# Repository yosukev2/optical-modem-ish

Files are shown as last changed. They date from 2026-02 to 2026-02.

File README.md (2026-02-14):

了解。以下はそのまま `README.md` に貼れる形で作りました（**W1時点のREADME**として、W2以降で埋める前提の“空枠”も入れてあります）。

---

# Optical Link Modem (RP2040 + TOSLINK)

## 目的（1〜2行）

RP2040(Pico) と TOSLINK 光モジュールを使い、**「基板 + 組み込みFW + 検証（BER/PER・ログ）+ 実務ドキュメント」**まで揃えた、実務代替ポートフォリオとしての“光リンクモデム”を実装する。

---

## 構成（箇条書き）

* **PC**

  * USB/シリアルで CLI 操作・ログ取得
* **MCU（RP2040 / Raspberry Pi Pico）**

  * フレーミング / 同期 / CRC / 再送 / 符号化モード切替
  * BER/PER 測定とログ出力
* **光モジュール（TOSLINK推奨）**

  * Tx：TOTX/TOTX系
  * Rx：TORX/TORX系
* **光ファイバ（TOSLINKケーブル）**

  * Tx↔Rx を接続（短距離から開始）
* **ベースボード（Pico載せ替え可能）**

  * 3.3V電源（LDO/DC-DC）＋保護＋テストパッド
  * Tx/Rxモジュール搭載、計測点、拡張I/F

> 構成図（W22で差し替え予定）
> `docs/onepager_A4.pdf` に掲載予定

---

## 成果物一覧（実務扱いに変える成果物）

* **Bring-up手順**：`docs/bringup.md`

  * 電源 → クロック → I/O → Tx → Rx → リンク確立（写真・測定値つき）
* **テスト計画**：`docs/test_plan.md` / `docs/test_matrix.csv`

  * 条件・合否基準・ログ形式・自動化手順
* **不具合チケット（最低3件）**：`docs/bugs/`（またはGitHub Issues）

  * 再現 → 切り分け → 修正 → 再発防止 → テスト追加
* **A4一枚サマリ**：`docs/onepager_A4.pdf`

  * 構成図、担当範囲、検証結果（BER/PER）、学び、残課題

---

## 週次マイルストーン（W1〜W4）

### W1：要件固定＆“実務の型”を作る

* `docs/spec.md`：仕様凍結（物理/レート/フレーム/CRC/再送/ログ）
* リポジトリ構成確定（docs/fw/hw/tools）
* Issueテンプレ追加（bug運用の型）

### W2：最速プロトで光リンクを“観測”する

* ブレッドボード等で Tx/Rx を暫定配線
* GPIOトグル → 受光出力変化を観測（ロジアナ/オシロ推奨）
* `docs/bringup.md` に配線図・測定ポイントを追記
* `fw/blink_optical/`：トグル＋Rxカウント最小FW

### W3：フレーム + CRC を“最低限のモデム核”として実装

* フレーム：`Preamble | Sync | Header | Length | Payload | CRC`
* 送受信バッファ（リング）・エラー処理
* `tools/test_crc.py`：CRCの既知ベクタテスト
* `docs/protocol.md`：プロトコル仕様

### W4：同期（プリアンブル検出）＋PER計測で“モデム顔”にする

* 受信同期：プリアンブル検出→sync→header→payload→CRC
* PER測定（連番pkt、欠番/CRC NG分類）
* ログフォーマット確定：`docs/log_format.md`
* READMEにデモ手順追記（このREADMEの空枠を埋める）

---

## デモ手順（W2で追記する前提の“空枠”）

> ※ここは W2 以降に更新予定

### 1) 配線・準備

* [ ] Tx/Rxモジュールの接続（Vcc/GND/IN/OUT）
* [ ] TOSLINKケーブルで Tx → Rx 接続
* [ ] Pico をPCに接続（USB）

### 2) ビルド＆書き込み

* [ ] `fw/` のビルド手順（例：CMake / pico-sdk）
* [ ] Picoにフラッシュ

### 3) 動作確認（最小）

* [ ] Txトグルを出す
* [ ] Rxでエッジカウント
* [ ] ロジアナで Tx入力とRx出力を観測（任意）

### 4) 測定（予定）

* [ ] PER測定（`test per ...`）
* [ ] BER測定（`test ber ...`）
* [ ] ログ保存（CSV/JSONL）

---

## 必要機材

* **Raspberry Pi Pico（RP2040）** ×2（送受信を分けるなら2枚推奨）
* **TOSLINK Tx/Rx モジュール**
  * 推奨：Toshiba系（TOTX/TORX など 3.3V対応の系統優先）
  * 代替：PLT133系（3〜5V/TTL互換と記載の系統）
* **TOSLINK光ファイバケーブル**（短め推奨）
* **ロジックアナライザ**（Tx入力/Rx出力の波形確認）
* **オシロスコープ**（電源リップル・受光ノイズ確認）⇒使用したいが、一旦保留
* **可変電源＋電流制限**（基板Bring-upの安全性UP）⇒使用したいが、一旦保留

---

## リポジトリ構成（予定）

```
.
├─ docs/            # 仕様・設計・bring-up・テスト・レポート
├─ fw/              # RP2040 firmware（link/protocol/cli/test）
├─ hw/              # KiCad（schematic/pcb/gerber）
├─ tools/           # PC側スクリプト（sweep/log/plot 等）
└─ sample_logs/     # サンプルログ（後で追加）
```

---

## ライセンス

* TBD（例：MIT / Apache-2.0）

---

## 状態

* W1（仕様凍結＆実務の型づくり）進行中

---

必要なら次に、**READMEの冒頭に入れる「3行で刺す要約」**と、`docs/spec.md` の雛形（項目埋め済み）も同時に作って、W1の成果物を一気に揃える形にできます。

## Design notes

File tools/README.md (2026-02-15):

# tools/README.md
目的：ログ取得・PER/BER集計に加えて `circuit_synth` を使うため、`uv` でPython環境を固定する。

---

## 1. Python方針
- 依存管理：`uv`（`pyproject.toml` + `uv.lock`）
- Python：3.12 以上（`circuit_synth` の要件）
- 仮想環境：`tools/.venv`（`uv` が自動作成）

---

## 2. セットアップ
1) `tools` に移動  
2) 依存を同期  
   `uv sync`  
3) 動作確認  
   `uv run python -c "import circuit_synth as cs; print(cs.__version__)"`

---

## 3. 主要パッケージ
- circuit_synth（回路生成）
- pyserial（UARTログ取得）
- pandas（CSV集計）
- rich（CLI表示）

---

## 4. 補足
- PDF出力を使う場合は `reportlab` が必要なため、必要時に `uv add reportlab` を実行する。

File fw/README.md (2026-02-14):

# fw/README.md
目的：W2で "必ずビルドして.uf2を作る" ための最小手順を固定する。

---

## 1. 前提
- OS：Windows（PowerShell想定）
- ボード：Raspberry Pi Pico (RP2040)
- SDK：pico-sdk **2.2.0 固定**（タグ固定。master追従しない）

---

## 2. 依存（インストール済みチェック）
必要：
- Git
- CMake
- Ninja（推奨）
- ARM GCC toolchain（arm-none-eabi-gcc）
- Python（ビルド補助で使う場合あり）

---

## 3. pico-sdk を取得（サブモジュール or 直clone）
推奨：repo直下に external/pico-sdk として置く

例：
- external/pico-sdk を作って clone
- tag 2.2.0 に checkout

---

## 4. ビルド手順（最小）
例：fw/blink をビルドする想定（W2はLED点滅でOK）

1) ビルドディレクトリ作成
2) cmake configure
3) ninja で build
4) .uf2 を Pico に書き込み

[TODO] 実際の fw 構成に合わせてコマンドを確定する

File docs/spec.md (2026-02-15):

# Spec: Optical Link Modem (RP2040 + PLT133/PLR237)

> SPEC FREEZE (v0.1 / W1)  
> 本仕様は原則確定版。変更が必要な場合は Issue 経由で、理由・影響範囲・代替案・必要なテスト更新（test_plan / log_format 等）を明記した後に反映。

## 0. 関連ドキュメント（正）
- Protocol詳細（フレーム/同期/状態遷移）: `docs/protocol.md`
- ログ列定義（CSVの一次ソース）: `docs/log_format.md`
- テスト計画（試験ID/合否基準/条件マトリクス）: `docs/test_plan.md`
- CLI仕様: `docs/cli.md`
- 部品根拠（データシート抜粋/購入リンク/代替候補）: `docs/parts.md`
- ハードウェア契約の正本（ネット名/IF契約/生成運用）: `docs/hw/`

---

## 1. 目的
PLT133（Tx）/PLR237（Rx）のTOSLINK系モジュールを用いた低速の光リンクで、“モデムっぽい”通信FW（フレーミング/同期/CRC/再送/符号化モード切替）と、検証（BER/PER・ログ）および 実務ドキュメント（Bring-up/Test plan/Bug tickets/Onepager）までを揃える。

## 2. スコープ
- 光リンク（短距離）での 双方向 送受信（最低2ノード、Tx/Rxを両方搭載）
- “モデムっぽさ”は ファーム側で実装（物理の難所は極力回避）
- 初期は「動く」より 測れる・再現できる・壊れ方が定義される を優先する

---

## 3. 固定仕様（W1で凍結する値）

### 3.1 ハード前提（部品・電圧）
- MCU: RP2040（Raspberry Pi Pico）
- Optical modules（Photolink系）
  - Tx: PLT133/T10W
  - Rx: PLR237/T10BK
- 部品の採用理由・一次ソース（データシート抜粋）・購入リンク・代替候補は `docs/parts.md` を正 とする（specは凍結運用のまま）
- GPIO Logic level: 3.3V
- Optical module Vcc:
  - Tx(Vcc)=3.3V
  - Rx(Vcc)=3.3V
  - 理由：Rx出力をRP2040の3.3V入力範囲に収めるため（Rxを5V駆動する場合はレベルシフタ必須。v0.1では禁止）

### 3.2 リンク形態
- Nodes: 2ノード想定（双方向 / Tx+Rx）
- Medium: TOSLINK光ファイバ

### 3.3 データレート
- 対応レート（設定可能）: 0.5 / 1 / 2 Mbps
- 初期運用（W2〜W4）: 0.5 Mbps 固定（安定化優先）

### 3.4 フレーム（概要）
- Frame format: `Preamble | Sync | Header | Length | Payload | CRC`
- Payload length: 0〜256 bytes（最大256B）
- CRC coverage: Header + Length + Payload（Preamble/Syncは除外）

### 3.5 同期（Preamble / Sync）
- Preamble
  - Pattern: 0x55 repeated
  - Count: 32 bytes（固定）
- Sync byte
  - Value: 0xD5（固定）
- 受信失敗時（CRC NG / 長さ不正 / sync不一致 等）は SYNC探索へ戻る（RESYNC）

### 3.6 Header（固定レイアウト）
Headerは 4 bytes固定。

| byte | name | size | meaning |
|---:|---|---:|---|
| 0 | version | 1 | 固定値 0x01（v0.1） |
| 1 | flags | 1 | mode/rate/power/ack等のビットフィールド |
| 2 | seq | 1 | 下位4bitのみ使用（0〜15）、上位4bitは0固定 |
| 3 | type | 1 | 0x01=DATA, 0x02=ACK, 0x03=NACK, 0x10=TEST |

#### flags（ビット割り当て）
- bit0-1: rate_id
  - 00=0.5Mbps, 01=1Mbps, 10=2Mbps, 11=reserved
- bit2: mode
  - 0=Mode A(NRZ), 1=Mode B(Manchester)
- bit3-4: power
  - 00=0, 01=1, 10=2, 11=reserved
- bit5: ack_req
  - 0=ACK不要, 1=ACK要求
- bit6-7: reserved（0固定）

### 3.7 CRC
- CRC Algorithm: CRC-16/CCITT-FALSE
  - width = 16
  - poly = 0x1021
  - init = 0xFFFF
  - refin = false
  - refout = false
  - xorout = 0x0000
- CRCの付与順（送信バイト順）: MSB first（big-endian）
  - 例：CRC=0x1234 → `0x12 0x34`
- CRCの入力順: Header → Length → Payload の順にバイト列を投入

### 3.8 再送（ARQ）
- ARQ: Stop-and-Wait
- seq: 4bit（0〜15）（Header.seq下位4bit）
- timeout: 20ms
- retry上限: 5回
- retry超過: link_down を宣言（statusに反映し、再同期を試みる）

### 3.9 符号化モード（PHY coding）
- Mode A: NRZ（W3〜で利用）
- Mode B: Manchester（W8で実装。仕様としてはv0.1で固定）
- モードの通知/切替: `flags.mode`

### 3.10 測定（品質評価）
- PER: packet error/loss rate（連番パケット、欠番/CRC NG を分類）
- BER: PRBS7（余力でPRBS15）

### 3.11 ログ（CSV）
- 保存先: `logs/`
- 命名規則: `logs/YYYYMMDD_runXX_<mode>_<rate>_<power>_<note>.csv`
  - 例：`logs/20260105_run01_A_0p5M_p1_short.csv`
- 列定義: `docs/log_format.md` を正（specは参照のみ）

---

## 4. 非目標（Non-goals）
- FEC（前方誤り訂正）
- 暗号化（Encryption）
- 高速化（>2Mbps）
- 長距離・高信頼向けのアナログ最適化（TIA設計、受光アンプ設計 等）
- 厳密な規格準拠（S/PDIF等）

---

## 5. インターフェース

### 5.1 PC ↔ MCU
- Control/CLI: USB CDC（優先）
  - 代替: UART
- Log output: USBまたはUART（制御と分離してもOK）

### 5.2 MCU ↔ Optical
- Tx: GPIO -> PLT133 IN
- Rx: PLR237 OUT -> GPIO input
- 実装方針: Rxは PIO or IRQ（W3で確定）

---

## 6. 合格条件（W26の最終成果物：1段落）
W26時点で、基板のBring-up手順（電源→I/O→リンク）が写真・測定値つきで再現可能であり、テスト計画（条件・合否基準・ログ形式）に基づいて BER/PERを自動測定しCSVログとして保存できること。さらに、不具合チケットを最低3件（再現→切り分け→修正→再発防止→テスト追加まで）完了しており、代表条件での測定結果（数値）をまとめた A4一枚サマリを提出できる状態であること。

---

## 7. 変更履歴
- 2025-12-30: 初版完成

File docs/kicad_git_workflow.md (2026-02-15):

# KiCadをGitで管理する運用
このドキュメントは、KiCadプロジェクトをGit/GitHubで安全に管理・レビューするための運用ルールを1箇所に集約したものです。  
**目的は「差分が追える」「衝突を避ける」「別PCでも再現できる」状態を維持すること**です。

---

## 1. リポジトリ構成（配置の原則）
**原則：KiCadプロジェクトは `hw/` 配下に置く。規約は `docs/` に集約する。**

hw/
  hw.kicad_pro
  hw.kicad_sch # Step00（正本）
  step01_power.kicad_sch # Step01以降
  (必要になったら) hw.kicad_pcb
  (必要になったら) sym-lib-table
  (必要になったら) fp-lib-table
lib/ # 外部ライブラリは必要時のみ（追加は別Issue）
docs/
  kicad_git_workflow.md # このファイル（運用の単一の真実）
  hw/
    nets.yml # ネット名辞書の正本（canonical）
    interface_contract.yml # Step間I/F契約の正本
    circuit_synth_policy.md # Circuit-Synth運用規約の正本
out/ # 生成物（原則git管理しない）

注意：`out/` は生成物置き場。普段はGitに入れない（リリース時だけ例外ルールあり）。

---

## 2. Gitで追跡するもの / ignoreするもの
KiCadはGUI編集だが、主要成果物はテキストファイルでありGit管理が可能。  
ただし個人環境ファイルや自動生成・バックアップ類は差分ノイズになるため除外する。

### 2.1 追跡（commit）対象（基本）
- `hw/*.kicad_pro`（プロジェクト設定。共有に有用なため原則追跡）
- `hw/*.kicad_sch`（回路図。Step分割前提）
- `hw/*.kicad_pcb`（基板。導入後は追跡）
- `hw/sym-lib-table` / `hw/fp-lib-table`（ライブラリ参照固定に有用。必要になったら追跡）
- `docs/` 配下（規約、設計ノート、意思決定ログ）

### 2.2 除外（ignore）対象（必須）
- `*.kicad_prl`（ユーザーごとの状態。必ず除外）
- `*-backups/`（バックアップフォルダ）
- `_autosave-*`（自動保存）
- `*.lck`（ロックファイル）
- `out/`（生成物置き場）
- `hw/out/`（`hw/` 配下の生成物置き場）

---

## 3. 回路図の分割方針（Step運用）と同時編集ルール
### 3.1 分割方針（Step01〜）
原則：回路図はStep単位のファイルに分割し、変更範囲を小さくする。

- `hw/hw.kicad_sch`：Step00（最上位／俯瞰と階層シートの接続点）
- `hw/step01_power.kicad_sch`：電源（W3でこのファイルを作る方針）
- `hw/step02_*`：I/OやTOSLINK周辺
- `hw/step03_*`：MCU周り
- 以降、必要に応じて `stepNN_*` を追加

命名規則：
- `hw/stepNN_<short>.kicad_sch`（NN=01,02... / shortは小文字スネーク）
- CIでは `^hw/step[0-9][0-9]_[^/]+\.kicad_sch$` を強制する（`hw/hw.kicad_sch` はStep00として別扱い）
- 一度決めたファイル名は原則変更しない（差分追跡コストを上げるため）

### 3.2 同時編集しないルール（コンフリクト回避の最重要）
- 同じ `.kicad_sch` を複数ブランチで同時に編集しない
- 特に `.kicad_pcb` は衝突が解消しづらいため、次を原則とする：
  - 基板ファイルは担当者固定、または順番制（同時編集禁止）

### 3.3 Step00への統合ルール（参照の追加）
- Step01〜を作っただけではStep00に自動反映されないため、**統合は `hw/hw.kicad_sch` に階層シート参照を追加して行う**
- `hw/hw.kicad_sch` は統合点なので、**同時編集禁止**（衝突回避）

**推奨運用（統合PR方式）**
- 各Step作成PR（例：`hw/step01_power.kicad_sch` 追加/更新）では **`hw/hw.kicad_sch` を触らない**
- Stepが揃ったタイミングで、最後に **「統合PR」** を作り、`hw/hw.kicad_sch` に **参照（階層シート）をまとめて追加**する
- 統合PRの判定は **PRラベル `integration-pr` が付いているかどうかのみ** で行う

注意：
- ここでの「統合」は **KiCadでの参照追加**であり、**KiCad上でファイル同士を“マージ”する操作はしない**

---

## 4. ライブラリ方針（標準優先 / 外部追加は最小）
### 4.1 基本方針
- KiCad標準ライブラリを優先
- 外部ライブラリ追加は最小限にする（差分が追いにくくなるため）

### 4.2 外部ライブラリを追加する場合（必須ルール）
- 必ずIssueを分けて実施する（このIssueではやらない）
- 追加する場合はプロジェクト内に同梱し、環境依存を避ける（例：`hw/lib/`）
- 追加時に必ず記録する（PR本文またはdocsの追記）
  - 追加理由
  - 出典（URL）
  - バージョン/コミットSHAなど識別子

---

## 5. PR運用（1PR=1Step）とレビュー証跡
### 5.1 1PR=1Step の意味
- 1つのPRでは基本1つのStepファイル（例：step01_power）だけを変更する
- PRが承認されたらGitHub上でマージして積み上げる
  - KiCad上で“マージ”操作はしない
- Stepファイル（step01/step02…）は順次マージで前進し、Step00（`hw/hw.kicad_sch`）への参照追加は「統合PR」でまとめて行う

### 5.2 PRガードレールCI（差分ベース）
PRでは `git diff --name-status <base> <head>` の差分だけを対象に、次を強制する。

- 禁止ファイル/パスを含む差分はFAIL
  - `*.kicad_prl`
  - `*/<something>-backups/*`
  - `_autosave-*` を含むファイル名
  - `*.lck`
  - `out/` 配下
  - `hw/out/` 配下
- 追加（`A`）・改名（`R*`）された `hw/` 配下の `.kicad_sch`（`hw/hw.kicad_sch` を除く）は
  `^hw/step[0-9][0-9]_[^/]+\.kicad_sch$` に一致しない場合FAIL
- `hw/hw.kicad_sch` が差分に含まれるPRは、ラベル `integration-pr` が無ければFAIL
  - `integration-pr` がある統合PRのみ、Step00変更を許可
- 変更された `hw/*.kicad_sch`（追加/変更/改名）だけに対して ERC を実行し、`error=0` かつ `warning=0` を必須化
  - 実装スクリプト: `scripts/ci/erc_changed_gate.sh`
  - 判定対象は差分ベース（`BASE_SHA` と `HEAD_SHA` の比較）

### 5.3 PRに必ず添付する“証跡”（Evidence）
GUI編集のため、差分だけだとレビューが難しい。  
そのため、PRには最低限の証跡を添付してレビュー可能性を上げる。

必須（推奨）：
- 変更したStepの回路図PDF（またはスクショ）
- ERC結果（PASS/FAILが分かるスクショ/ログ）
- What（何を変更したか）/ Why（なぜ必要か）を短文で

基板がある場合（推奨）：
- DRC結果（PASS/FAILが分かるスクショ/ログ）
- 基板レンダ画像（表/裏）

---

## 6. コンフリクト（衝突）時の原則対応
原則：無理にテキストマージで解決しない。KiCadで開いて直して解決する。

- Gitでコンフリクトが出たら、まず「同時編集が起きた」ことを確認し、再発防止（担当/順番）を調整
- 解決手順（原則）
  1. 片方の変更をベースにする（どちらを採用するか決める）
  2. KiCadでファイルを開き、必要な変更を反映
  3. ERC/DRC（該当する場合）を再確認
  4. コミットして解決

---

## 7. 製造リリースの例外ルール（Gerber等の扱い）
普段は `out/` をGit管理しないが、製造に出した瞬間の成果物は再現可能な形で固定したい。

以下のいずれかを採用（プロジェクトで統一すること）：
- GitHub Releaseに、Gerber/Drill/BOM等を添付（推奨）
- タグを打ち、リリース成果物をArtifactsとして保存（推奨）
- 例外的に `release/<date>_revX/` のようなフォルダにコミット（必要時のみ）

どれを採用するかは別Issueで決めても良い（本MDでは方針のみ提示）。

---

## 8. PR前の最小手順（ローカル証跡生成）

PRを出す前に、ローカルで証跡（PDF/ERC/DRC）を生成して内容を確認する。
生成した証跡はActionsのArtifactsと照合可能。

### 8.1 前提条件
- KiCad 8.0以降がインストールされていること
- `kicad-cli` にPATHが通っていること（コマンドプロンプトで `kicad-cli version` が実行できる）

### 8.2 1コマンド実行（PowerShell）

```powershell
# リポジトリルートで実行
.\scripts\kicad\gen_evidence.ps1 -ProjectPath "hw/hw.kicad_pro"
```

### 8.2.1 変更シートだけERCゲートを再現（bash）

```bash
# BASE/HEAD はCIと同じく差分比較で指定
bash scripts/ci/erc_changed_gate.sh "$BASE_SHA" "$HEAD_SHA"
```

### 8.3 生成されるファイル

出力先: `hw/out/`

| ファイル | 内容 |
|---|---|
| `{名前}.pdf` | 回路図PDF |
| `{名前}_erc_all.json` | ERC結果（全severity） |
| `{名前}_erc_error.json` | ERC結果（エラーのみ、artifact確認用） |
| `erc/{名前}_erc_changed.json` | 変更シートERCゲート結果（error/warning判定用） |
| `{名前}_drc.json` | DRC結果（pcbがある場合のみ） |

例: `hw/hw.kicad_sch` の場合 → `hw/out/hw.pdf`, `hw/out/hw_erc_all.json`, `hw/out/hw_erc_error.json`, `hw/out/erc/hw_erc_changed.json`

### 8.4 hw/out/ はコミットしない

`hw/out/` は `.gitignore` で除外済み。生成後に `git status` で表示されないことを確認する。

```powershell
git status
# hw/out/ が表示されなければOK
```

### 8.5 Actions Artifactsとの照合チェック

PRをpushすると、GitHub ActionsがArtifacts (`kicad-pr-{PR番号}`) を生成する。
ローカル生成物とActionsの出力が整合していることを以下で確認できる：

- [ ] **ファイル名が一致**: ローカルの `hw/out/{名前}.pdf` と Artifacts の `{名前}.pdf` が同じ命名規則
- [ ] **ERC結果の整合**: ローカルでPASSならActionsでもPASS（エラーがあればActionsも失敗する）
- [ ] **DRC結果の整合**: pcbがある場合、ローカルとActionsで同じ `{名前}_drc.json` が生成される

注意: ActionsではPNG（`pdftoppm`）も生成されるが、ローカルでは省略している（PDF確認で十分）。

---

## 9. 最小チェックリスト（運用の守り）
- [ ] KiCadプロジェクトは `hw/` 配下にある
- [ ] `*.kicad_prl` / `*-backups/` / `_autosave-*` / `*.lck` / `out/` / `hw/out/` はGitに入れない
- [ ] Step00正本は `hw/hw.kicad_sch` とし、通常PRでは触らない（統合PR + `integration-pr` ラベル時のみ許可）
- [ ] 回路図（Step01以降）は `^hw/step[0-9][0-9]_[^/]+\.kicad_sch$` の命名規約を守る
- [ ] ハード契約（ネット名/I/F契約/Circuit-Synth運用）は `docs/hw/` の正本に従う
- [ ] PRは基本 1PR=1Step で小さく積み上げる
- [ ] PRに回路図PDF（またはスクショ）とERC/DRC結果を添付する
- [ ] 外部ライブラリ追加は必ずIssueを分け、理由/出典/版を残す
- [ ] コンフリクトはKiCadで開いて直し、ERC/DRCで再確認して解決する

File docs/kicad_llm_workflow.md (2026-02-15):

# LLM前提のKiCad開発運用（空ファイルで型を固定 → 差分で回路を作る）
このドキュメントは、KiCad設計をLLMと一緒に進めるための運用ルールを 1箇所に集約したものです。  
目的は「壊れない」「差分が読める」「初心者でも手戻りが少ない」開発フローを作ることです。

---
## 0. このプロジェクトの固定事項（LLMが絶対に守る“型”）
- プロジェクト名（= 既定ファイル名の基準）は `hw` とする  
  - 例：`hw/hw.kicad_pro` / `hw/hw.kicad_sch` / （導入後）`hw/hw.kicad_pcb`
- Step00（トップ/統合点）は `hw/hw.kicad_sch` とする（改名しない）
- Stepファイルは `hw/stepNN_<short>.kicad_sch` 形式
  - W3の最初の対象は `hw/step01_power.kicad_sch`

## 1. 方針の結論（最重要）
- 0からの `.kicad_sch` 全文生成は不安定  
  KiCadのバージョン差・ヘッダ構造・UUID・ライブラリ参照などで「開けない／壊れる」リスクが高い。
- 空ファイル（雛形）で型を固定した上で、LLMは追記（差分生成）に使う  
  人がKiCadで作った“正しいフォーマット”を土台にすることで、LLMの成功率が上がる。

---

## 2. 役割分担
### 人がやる（必須）
- KiCadで 空プロジェクトを作る
- `hw/step01_power.kicad_sch` など 空のStepファイルを作る（雛形）
- KiCadで開いて 最終確認・微修正する
- ERC/DRCの 最終判断（PASS/FAIL、許容する警告の判断）

### LLMがやる（得意領域）
- 回路案の提案（構成、部品候補、注意点）
- チェックリスト（見落とし防止）
- 雛形を壊さない前提で、追記後の `step01_power.kicad_sch` 全文を生成する
- PRレビュー（PDF/スクショ/ログを見て指摘・改善提案）

---

## 3. 最小運用フロー（Step単位）
### 3.1 初回のみ（型を固定する）
1. KiCadで `hw/` 配下に新規プロジェクト作成
2. `hw/hw.kicad_sch` を 空で作成（雛形）
3. Step00（`hw/hw.kicad_sch`）雛形ができた状態をコミット

### 3.2 以降（LLMは差分で回路を作る）
1. LLMに入力する
   - 雛形（空の `step01_power.kicad_sch` の全文）
   - このドキュメントの運用ルール（最低：差分生成ルール＋命名規約）
   - 作りたい回路の要件（例：VBUS→+5V→+3V3、デカップリング等）
2. LLMに「追記後の `step01_power.kicad_sch` 全文」を出力させる
3. 人がKiCadで開く
   - ERCで確認
   - 見た目・配線・部品の妥当性を確認
   - 必要なら微修正
4. PR作成 → GitHubでマージ

---

## 4. “差分生成”のルール（壊さないための制約）
LLMに必ず守らせる制約：

- 既存ヘッダ / バージョン / 構造を変更しない（必要最小限の追記のみ）
- UUIDは既存を変更しない／重複させない
- 座標や並びを無意味に変更しない（差分ノイズ禁止）
- ライブラリ参照は標準優先（外部追加は別Issueで実施）

---

## 5.電源ネット命名規約（初版 v0.1）
目的：電源系のネット名を最初に固定し、回路図分割（Step01〜）でも混乱・誤配線・差分ノイズを減らす。  
原則：電源ネット名はこの規約で“唯一の正”とし、別名を増やさない。
正本: `docs/hw/nets.yml`（この節は運用説明）。

### 1) 標準電源ネット（採用する名前）
本プロジェクトで使用する標準電源ネット名は以下：

- `VBUS_IN`：USB（または外部）から入ってくる生のVBUS。保護/フィルタ前の入力点。
- `VBUS_PRO`：保護回路（Polyfuse/TVS等）通過後、LDO入力手前のVBUSノード。
- `+5V`：5Vレール。保護・スイッチ・ヒューズ・フィルタ後の「使ってよい5V」。
- `+3V3`：3.3Vレール。LDO/レギュレータ出力の主電源。
- `GND`：グランド（0V基準）。基本は単一 `GND` に統一。

> 重要：`5V`（プラスなし）や `3V3`（プラスなし）等の近い名前を混在させない。  
> 常に `+5V` / `+3V3` を使う。
> `VBUS_PROT` は旧表記。新規記述では `VBUS_PRO` に統一する。

### 2) 命名の適用ルール（いつ使うか）
- USBコネクタ直後のVBUSは `VBUS_IN`
  - 例：コネクタVBUS → ESD/ヒューズ/スイッチ前 = `VBUS_IN`
- 保護後でLDO入力に入るVBUSは `VBUS_PRO`
  - 例：ヒューズ後、TVS後、LDO IN手前 = `VBUS_PRO`
- 5Vを「回路で利用するレール」として配る点以降は `+5V`
  - 例：ヒューズ後、電源スイッチ後、フィルタ後 = `+5V`
- LDO/レギュレータの出力は `+3V3`
  - 例：レギュレータOUT → デカップリング → 配電 = `+3V3`
- グランドは常に `GND`  
  - アナログ/デジタル分離を最初からしない（必要になったら別Issueで導入）。

### 3) 分岐・派生名のルール（増やす条件を明確化）
原則：派生名（例：+5V_USB, +3V3_AUX）を増やさない。  
例外：以下のいずれかが必要になった時のみ、別Issueで導入する。

- 電源系統が物理的に別（別レギュレータ/別バッテリ/別電源入力）
- 電源シーケンス・スイッチ制御でレールを明確に分ける必要がある
- 測定やノイズ対策で明確に別レールとして扱う設計判断がある

導入時の派生名規則（採用する場合）：
- 形式：`+5V_<用途>` / `+3V3_<用途>`（用途は小文字スネーク推奨）
- 例：`+5V_usb`、`+3V3_rf`（※導入は必ず別Issue＋理由明記）

### 4) デカップリングと電源シンボルの扱い
- デカップリングの電源ピンは、必ず上記の標準ネット名に接続する
- 可能なら「電源シンボル（Power Symbol）」も標準名に合わせる
- LLMに回路を追記させる場合も、電源ピンが標準名になっているかを最優先で確認する

### 5) レビュー観点（最小チェックリスト）
PRレビュー（人/LLM共通）で必ず確認する：
- [ ] `VBUS_IN` / `VBUS_PRO` / `+5V` / `+3V3` / `GND` 以外の近い電源名が増えていない
- [ ] `VBUS_IN` と `+5V` の境界が「保護/フィルタ/スイッチ後」になっている
- [ ] レギュレータ出力が `+3V3` に統一されている
- [ ] `GND` が分裂していない（意図がある場合は別Issue）

### 6) 変更ルール（この規約の更新）
- 新しい電源レール名を追加したい場合は、必ずIssueを作る
- 追加時に記録すること：
  - 追加理由（なぜ分ける必要があるか）
  - 追加するネット名
  - どこからどこまでがそのレールか（境界の定義）

---

## 6. PRレビューの“証跡”要件（LLMレビューを強くする）
PRには最低限、以下を添付する（LLMレビューもここを見る）：
- 変更したStepの 回路図PDF（またはスクショ）
- ERC結果（スクショ/ログ）
- What/Why（短文でOK）

---

## 7. 例外・注意（初心者向け）
- `.kicad_pcb` は衝突しやすいので 同時編集を避ける  
  原則：担当者固定 or 順番制
- コンフリクト発生時は テキストで無理に直さない  
  KiCadで開いて修正し、ERC/DRCで再確認して解決する

---

## 8. Done（受け入れ条件 / Acceptance Criteria）
この `docs/kicad_llm_workflow.md` に以下が明記されていること：

- 「0からは不安定」「空ファイルで型固定→差分生成が現実解」の結論
- 人/LLMの役割分担
- 初回セットアップ（空プロジェクト・空stepファイル作成→コミット）
- 差分生成の制約（壊さないルール）
- 電源ネット命名規約（`VBUS_IN / VBUS_PRO / +5V / +3V3 / GND`）
- PRに添付する証跡（PDF/ERC/要約）
- 初心者が読んで、同じ手順で運用を開始できる程度に簡潔である

---

## 9. Scope（範囲）
- 運用ドキュメント（MD）の作成のみ

---

## 10. Notes（メモ）
- LLMは「文章・チェック・レビュー」に強い一方、「KiCadの内部形式を0から完璧に再現」は不安定。
- 雛形（空sch）をKiCadで作って“型”を確定させることで、LLMは壊しにくくなり成功率が上がる。
- 証跡（PDF/ERC）をPRに添付すると、人もLLMもレビュー精度が上がる。

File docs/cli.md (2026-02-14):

# CLI (Command List)

## 目的
PCから設定・測定・ログ保存を一連で実行できるようにする（実務っぽさの“顔”）。

---

## コマンド候補（W1テンプレ）
### help
- `help`
  - コマンド一覧表示

### get status
- `get status`
  - mode / rate / power / counters（crc_fail, retries, timeouts...）を表示

### set rate
- `set rate <bps>`
  - 例：`set rate 500000`

### set mode
- `set mode <A|B>`
  - Mode A: NRZ(+scramble)
  - Mode B: Manchester

### set power
- `set power <0|1|2>`
  - 物理出力ではなく論理冗長（例：同一フレーム複数回送信等）

### test per
- `test per <N> <payload_len>`
  - 例：`test per 1000 64`

### test ber
- `test ber <duration_s>`
  - 例：`test ber 10`

### log start/stop
- `log start`
- `log stop`
  - ログ出力開始/停止

---

## 出力形式
- ステータス：人間が読めるテキスト + 重要値はCSVログにも出せると良い

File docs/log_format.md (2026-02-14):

# Log Format (measure log)

## 作業ステータス
>  **measureログ（PER/BER結果）** のみを作成。  
> eventログ（状態遷移・エラーなど）は **JSONLで追加**（このファイルではフォーマットのみ方針メモ）。

---

## 1. 目的
光リンク（TOSLINK系）モデム実装の評価で発生する **PER/BER測定結果** を、
後から再集計・比較・再現できる形で保存するための CSV 仕様を定義する。

- **measureログ**：PER/BER の結果（**1行 = 1測定**）
- **eventログ**：状態遷移・エラーなど

---

## 2. 対象ログ
### 2.1 measureログ（本仕様の対象）
- ファイル形式：CSV
- エンコード：UTF-8（BOMなし推奨）
- 改行：LF（CRLFでも可だが統一推奨）
- 区切り：カンマ `,`
- 1行 = 1測定（PER/BER）
- 先頭にヘッダ行あり（必須）

### 2.2 eventログ
- 形式候補：JSON Lines（JSONL）
- 例：状態遷移、リンクダウン、CRC異常、同期再獲得、再送理由など

---

## 3. 命名規則（確定）
### 3.1 ログファイル名
`logs/YYYYMMDD_runXX_<mode>_<rate>_<test>.csv`

- `YYYYMMDD`：日付（例：20251230）
- `runXX`：同日内の通し番号（例：run01, run02）
- `<mode>`：`A` / `B`
- `<rate>`：Mbps表記（小数は `p` を使う：例 `0p5Mbps`, `1Mbps`, `2Mbps`）
- `<test>`：`per` / `ber`

**例**
- `logs/20251230_run01_A_0p5Mbps_per.csv`
- `logs/20251230_run02_B_2Mbps_ber.csv`

> ※ `cable`（short/long）や電源条件などは「列」で持つ（ファイル名に埋め込まない）

---

## 4. CSV Columns（確定：measureログ）
### 4.1 列一覧（順序固定・snake_case）
| column | type | required | description |
|---|---:|:---:|---|
| timestamp_iso | string | ✅ | ISO8601（例：`2025-12-30T18:35:12.123+09:00`） |
| mode | enum | ✅ | `A` / `B` |
| rate_mbps | number | ✅ | 例：`0.5`, `1`, `2` |
| power_level | int | ✅(予約) | `0/1/2`（初期は常に `0` 想定） |
| cable | enum | ✅ | `short` / `long`（ケーブル条件のタグ） |
| test_type | enum | ✅ | `per` / `ber` |
| pkt_sent | int | PER:✅ / BER:推奨 | 送信パケット数 |
| pkt_recv | int | PER:✅ / BER:推奨 | 受信パケット数（有効フレーム） |
| pkt_lost | int | PER:✅ / BER:推奨 | 欠損数（欠番・未達などの定義は test_plan に合わせる） |
| crc_fail | int | PER:✅ / BER:推奨 | CRC NG 数（受信はしたが破損） |
| bits_total | int | BER:✅ / PER:空可 | BER測定に使った総ビット数（payload由来など、定義は test_plan に合わせる） |
| bits_err | int | BER:✅ / PER:空可 | 誤りビット数 |
| ber | number | BER:✅ / PER:空可 | `bits_err / bits_total`（計算結果を保存。再計算可能性のため分子分母も残す） |
| note | string | 任意 | 自由欄（例：`vcc=3.30, temp=22C, firmware=abc123`） |

#### 値のルール（重要）
- **必須列は必ず存在**し、ヘッダのスペルはこの表と一致させる（解析を壊さないため）。
- `test_type=per` のとき：
  - `bits_total,bits_err,ber` は空でもよい（空欄推奨。`0` 埋めは誤解を生むので避ける）
- `test_type=ber` のとき：
  - `bits_total,bits_err,ber` は必須
  - `pkt_*` / `crc_fail` は残してもよい（フレーム化して測るなら役立つ）
- `note` にカンマが入る場合は **ダブルクォートで囲む**（CSV標準のエスケープ）

---

## 5. 例（ヘッダ + ダミー1行）
### 5.1 ヘッダ行
timestamp_iso,mode,rate_mbps,power_level,cable,test_type,pkt_sent,pkt_recv,pkt_lost,crc_fail,bits_total,bits_err,ber,note

### 5.2 PERの例（1行）
2025-12-30T18:35:12.123+09:00,A,0.5,0,short,per,10000,9992,8,3,,,,"vcc=3.30, firmware=abc123"

### 5.3 BERの例（1行）
2025-12-30T18:41:05.004+09:00,B,2,0,long,ber,2000,2000,0,0,16000000,12,7.5e-7,"prbs=15, vcc=3.30"

---

## 6. sample_logs
- `sample_logs/example_per.csv` を作り、5.1 のヘッダ + 5.2 の1行を入れる（ダミーでOK）
- 解析スクリプト（後日）を作るとき、この sample を単体で読めることが「動作確認」になる
****

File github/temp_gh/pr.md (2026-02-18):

# TEMP_GH PR Draft

用途:
- gh接続できない時に、AIがPR草案と登録コマンドを書き出す出力ファイル。
- 人間は `PowerShell Command` をコピペしてPR作成する。

## Status
- mode: draft
- reason:
- pr_url:

## Title
(skill9_pr_submit が生成)

## Body File
- (skill9_pr_submit が生成)

## Body Preview
```markdown
(skill9_pr_submit が生成)
```

## PowerShell Command
```powershell
# skill9_pr_submit 実行後にここへ出力される
```

## Bash Command
```bash
# skill9_pr_submit 実行後にここへ出力される
```

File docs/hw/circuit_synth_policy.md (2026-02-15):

# Circuit-Synth運用ポリシー（正本）

## 目的
Circuit-Synth導入時に、生成物と手編集の責務を分離し、Step運用とレビュー再現性を維持する。

## 適用範囲
- 対象: 子シート（`hw/stepNN_*.kicad_sch`）
- 非対象: 統合点の `hw/hw.kicad_sch`（Step00）

## 基本ルール
- Step00（`hw/hw.kicad_sch`）は統合点として手書き維持する。
- 正本は生成スクリプト（`scripts/hw/` 配下）と入力定義ファイルとする。
- 生成された `.kicad_sch` は成果物としてコミットする。
- 生成物 `.kicad_sch` を直接手編集しない。変更は必ずスクリプト経由で再生成する。

## 再生成運用（雛形）
- 再生成コマンドは `scripts/hw/` 配下に配置する。
- 命名例: `scripts/hw/gen_step02.ps1` または `scripts/hw/gen_step02.sh`
- PRには、実行コマンドと再生成ログをEvidenceとして添付する。

## レビュー観点
- 変更差分が「入力定義/スクリプト変更」と「再生成結果」で対応していること
- 手編集起因の差分（配線/UUID/座標の不整合）が混入していないこと
- Step00への変更は統合PRルール（`integration-pr` ラベル）に従うこと

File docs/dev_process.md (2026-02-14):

# Dev Process（運用ルール）

このリポジトリは「実務っぽく開発できること」を目的に、最低限の運用ルールを定める。

---

## ブランチ運用
- 常用ブランチは `main`。
- 変更は原則ブランチを切って行う：
  - `feature/<topic>`：機能追加
  - `fix/<topic>`：バグ修正
  - `docs/<topic>`：ドキュメント
  - `chore/<topic>`：雑務（CI/設定/運用）

例：
- `feature/per-ber-measure`
- `fix/crc-fail-on-long-cable`

---

## 1PRは小さく
- 1PRは「1目的」に絞る。
- 目安：レビューが10分で終わるサイズ。
- 大きくなる場合は PR を分割する（先にリファクタ、次に機能追加、など）。

---

## Definition of Done（DoD）
PRを `main` に入れる条件（最低ライン）：

1. **Whyが説明できる**
   - PR本文に「なぜ必要か」が書かれていること

2. **証拠がある**
   - ログ/スクショ/測定結果など、第三者が追体験できる証拠が添付されていること  
   - 例：PER/BERログ、リンク確立ログ、波形、端末出力

3. **必要なdocsが更新されている**
   - 仕様変更があるなら `docs/spec.md` / `docs/protocol.md` 等に反映
   - ログ形式変更なら `docs/log_format.md` を更新

4. **回帰テストが考慮されている**
   - バグ修正は原則、再発防止のテスト（手順 or 自動）を追加する
   - 少なくとも「どう再発を検知するか」をPRに書く

---

## Issue運用（最低限）
- バグは `bug` ラベルを付け、再現手順・証拠（ログ）を必須とする。
- 優先度は `P0/P1/P2` を付ける（迷ったらP1）。

---

## レビュー観点（セルフレビュー用）
- 変更は最小か（不要な差分が混ざっていないか）
- 破壊的変更はないか（互換性・ログ形式）
- ログ/証拠は十分か
- docs/test 更新漏れはないか

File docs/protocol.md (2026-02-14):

# Protocol: Framing / Sync / CRC

## 1. 目的
光リンク上で “モデムっぽさ” を成立させるための最小プロトコル（同期・フレーム・CRC・再送の前提）を定義する。

## 2. フレーム形式（箱）

### 2.1 Preamble
- Pattern: `0x55` repeated
- Count: TBD（例：16〜64 bytes）
- Purpose: 同期検出のための繰り返しパターン

### 2.2 Sync
- Value: TBD（例：`0xD5`）
- Purpose: フレーム開始の確定（preambleの後に続く印）

### 2.3 Header（例）
> ここは「最低限の箱」。W3で確定する

- `version` (1 byte)
- `flags` (1 byte): mode/rate/power/ack関連など
- `seq` (1 byte): Stop&Wait用（1bitでもbyteで持ってOK）
- `type` (1 byte): DATA/ACK/NACK/TEST etc.（任意）

### 2.4 Length
- 1 byte or 2 bytes（暫定：1 byte）
- payload length in bytes（0〜MAX）

### 2.5 Payload
- user data or test pattern (PRBSなど)

### 2.6 CRC
- CRC-16-CCITT（spec.mdに従う）
- Coverage: `Header + Length + Payload`
- Details（poly/init/refin/refout/xorout）はW3で確定

## 3. 同期（受信状態遷移の箱）
- SEARCH_PREAMBLE
- SEARCH_SYNC
- READ_HEADER
- READ_LENGTH
- READ_PAYLOAD
- READ_CRC
- VALIDATE / DROP / RESYNC

## 4. 再送（Stop-and-Waitの箱）
- DATA送信 -> WAIT_ACK
- ACKなら次へ / TIMEOUTなら再送 / NACKなら再送
- Retry limit: TBD（例：3回）

## 5. モード（符号化切替の箱）
- Mode A: NRZ (+ optional scramble)
- Mode B: Manchester
- Modeは `flags` で通知・切替

## 6. 未確定項目（To decide）
- preamble長、sync値
- header field確定
- CRCパラメータ確定
- ACK/NACK表現（type or flags）

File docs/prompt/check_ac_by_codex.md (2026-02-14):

あなたは「AC達成判定専用レビュワー」。入力は ISSUE_NUMBER のみ。
前提：判定対象は “今このローカルにある差分（HEAD＋未コミット含む）”。ghでPR探索はしない。
禁止：編集/コミット/プッシュ/Issue更新。読取りとコマンド実行のみ。

ISSUE_NUMBER=<ここに番号>

# 出力（厳守）
- repo / branch / status
- ACごとの判定（PASS/FAIL/UNKNOWN）＋Evidence（見たファイル/コマンド）
- 総合結論（OK/NG/要確認）＋次アクション

# 手順（実行してレポートを書け）
1) repoと状態
- REPO=$(gh repo view --json nameWithOwner -q .nameWithOwner)
- git status -sb
- git log -1 --oneline

2) Issue本文取得 → AC抽出
- gh issue view $ISSUE_NUMBER --repo "$REPO" --json number,title,url,body -q '.'
- 本文から「AC/受け入れ条件/Acceptance Criteria」を抽出し、AC1..Nとして列挙
  - 見つからなければ「ACなし」として暫定要件を本文から推定（暫定と明記）

3) ローカル差分の収集（証拠）
- git diff --name-status > /tmp/diff_names.txt
- git diff > /tmp/diff.patch
- 主要変更ファイルを上から5〜10個に要約（ACとの対応も推測）

4) AC判定（最重要）
各ACについて：
- PASS: 差分/ファイル内容から満たす証拠あり
- FAIL: 明確に不足
- UNKNOWN: 追加確認が必要（そのための最小コマンドを提示）
Evidenceは「ファイル名 + どこ（見出し/周辺の短い要約） + 実行コマンド」を必ず書く。

5) 総合結論
- FAILが1つでもあればNG
- UNKNOWNのみなら要確認（必要コマンド付き）
- 全PASSならOK
次アクションは“最小手戻り”で箇条書き。

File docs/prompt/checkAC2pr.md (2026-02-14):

あなたは実行エージェント。PR作成は「ACゲートがALL PASSの時だけ」許可される。
入力は ISSUE_NUMBER のみ。判定対象は “ローカル差分（未コミット含む・未追跡も含む）”。
禁止：Issue更新、rebase/merge、ファイル改変（レポート/PR本文の一時ファイル作成はOK）。
テンプレ必須：.github/pull_request_template.md が無ければPR作成しない。

ISSUE_NUMBER=<ここに番号>

# ===== 共通前提 =====
$ErrorActionPreference = "Stop"
gh auth status
$REPO = gh repo view --json nameWithOwner -q .nameWithOwner
git status -sb
if (!(Test-Path ".github/pull_request_template.md")) { Write-Host "テンプレ無し。PR作成中止"; exit 0 }

# ★差分判定：未追跡も含めて検出（git diff ではなく status を使う）
$porcelain = (git status --porcelain) | Out-String
if ([string]::IsNullOrWhiteSpace($porcelain)) { Write-Host "変更なし（未追跡も含めて0）。PR作成中止"; exit 0 }

# ★(B) TEMPは使わない：ワークスペース内 .codex/ に出力
$CODIR = Join-Path (Get-Location) ".codex"
New-Item -ItemType Directory -Force -Path $CODIR | Out-Null
$AC_REPORT = Join-Path $CODIR "ac_report_$ISSUE_NUMBER.txt"
$BODY      = Join-Path $CODIR "pr_body_$ISSUE_NUMBER.md"

# ===== 1) ACチェック（必須）→ レポート出力 =====
$ISSUE = gh issue view $ISSUE_NUMBER --repo "$REPO" --json number,title,url,body -q .
$lines = @()
$lines += "repo: $REPO"
$lines += "issue: #$($ISSUE.number)"
$lines += "url: $($ISSUE.url)"
$lines += ""
# ここで Issue本文からACを抽出し、ローカル変更（git status --porcelain と必要ならファイル内容）を根拠に判定して、
# 必ず次の形式の行を $lines に追加すること：
# - AC行は `AC1: PASS` のように 1行1AC（PASS/FAIL/UNKNOWNのみ）
# - 最終行は `AC_GATE: PASS` か `AC_GATE: FAIL`
# - もしACが本文に無い場合は FAIL 扱い（= AC_GATE: FAIL）
#
# その上で、$txt を作って Out-File で $AC_REPORT を作成せよ。

$txt = ($lines -join "`n")
$txt | Out-File -FilePath $AC_REPORT -Encoding utf8

# ===== 2) ゲート検証（機械的に / (C) 後続の別コマンドを出さず、この塊で完結） =====
# ★読み直しGet-Contentは使わず、今ある $txt をそのまま検証する
if ($txt -match ':\s+(FAIL|UNKNOWN)\b') {
  Write-Host "ACゲート不通過（FAIL/UNKNOWNあり）。PR作成中止。レポート: $AC_REPORT"
  exit 0
}
if ($txt -notmatch '(?m)^AC\d+:\s+PASS$') {
  Write-Host "AC行が見つからない（出力不備/未実施）。PR作成中止。レポート: $AC_REPORT"
  exit 0
}
if ($txt -notmatch '(?m)^AC_GATE:\s+PASS$') {
  Write-Host "AC_GATEがPASSではない。PR作成中止。レポート: $AC_REPORT"
  exit 0
}

# ===== 3) ここから先は“全PASS確定”した場合のみ =====
$ISSUE_TITLE = $ISSUE.title
# slugは英数字とハイフンのみ、空白→ハイフン、40文字程度に短縮
$SLUG = <Codexが生成>
$BRANCH = "m0/issue-$ISSUE_NUMBER-$SLUG"
$TITLE  = "M0 #$ISSUE_NUMBER: $ISSUE_TITLE"

# ブランチ作成/移動
if (git show-ref --verify --quiet "refs/heads/$BRANCH") { git switch $BRANCH } else { git switch -c $BRANCH }

# add/commit/push
git add -A
$staged = (git diff --cached --name-status) | Out-String
if ([string]::IsNullOrWhiteSpace($staged)) { Write-Host "ステージが空。PR作成中止"; exit 0 }
git commit -m "$TITLE"
git push -u origin $BRANCH

# PR本文（テンプレ埋め）
$T = Get-Content -Raw ".github/pull_request_template.md"
# テンプレ見出しは維持、置換できなければ各見出し直下に追記でOK：
# What: staged変更要約
# Why: Issueタイトル要約
# Evidence: "AC: PASS (gated)" + "ACレポート: $AC_REPORT"
# Impact: 推定でチェック
# 関連Issue: "Closes #<ISSUE_NUMBER>"
$T_filled | Out-File $BODY -Encoding utf8

# PR作成（base=main）
gh pr create --repo "$REPO" --base main --head "$BRANCH" --title "$TITLE" --body-file "$BODY"

# 出力
"AC_REPORT: $AC_REPORT"
"PR_BODY:   $BODY"
"BRANCH:    $BRANCH"
"SHA:       $(git rev-parse HEAD)"
"PR:        $(gh pr view --repo "$REPO" --json url -q .url)"
``
::contentReference[oaicite:0]{index=0}

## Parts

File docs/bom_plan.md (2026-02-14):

# bom_plan.md
目的：「光リンクを点灯・受信」

---

## 1. 光Tx/Rx（TOSLINK系）

### Everlight Photolink社
選択理由：送信と受信で、3.3V運用できるものを探した結果以下２つが入手可能であったため。

- Tx: PLT133/T10W
  - 電圧範囲（推奨）：2.7–5.5V（3.3V運用OK）  
  - 入手先： [マルツ](https://www.marutsu.co.jp/pc/i/13672939/)
  - 注意：VinがFLOATINGだとONになる（＝浮き対策必須、後述）  

- Rx: PLR237/T10BK
  - 電圧範囲（推奨）：3.0–5.5V（3.3V運用OK）
  - 入手先： [マルツ](https://www.marutsu.co.jp/pc/i/41237282/)
  - 出力：TTL互換

---

## 2. MCUボード方針

- 本命：Raspberry Pi Pico（RP2040）
- さらに代替：STM32 Nucleo / BluePill 等でも可（ただしW2〜W4はPico優先で進める）

決め：
- 基本的には、 **Pico**の方針
- 代替に切り替える条件：
  - Picoが入手不可 / PC環境でドライバが致命的に詰まる など

---

## 3. コネクタ/実装形状

TOSLINKの形状を2種に分類して記録する：

1) 基板直付け（Tx/Rxモジュールが基板に直で載る）
   - メリット：配線が短く安定、実験が再現しやすい
   - デメリット：基板が必要、実装がやや手間

2) ケーブル型（既製TOSLINK送受信や変換基板で延長）
   - メリット：とりあえず繋いで試せる
   - デメリット：配線が長くなりがち、GND/ノイズで詰まりやすい

方針：
基本的に基板直付けで行く方針

---

## 4. 必要ケーブル（短/長）

- short： 1 m（推奨 0.5〜1m）
- long ： 5 m（推奨 5〜10m）
目的：
- short：Bring-up（まず光る/受かる）
- long：耐性試験の入口（W4以降のBER/PERに効く）

---

## 5. “詰まりポイント”先回りメモ
- Txの入力(Vin)は浮くとONになる → pull-down必須
- Rx/TxはVcc近傍に0.1uFデカップリングを最短で置く
- W2は速度を上げない（まず低速・安定）

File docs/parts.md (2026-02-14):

# docs/parts.md — Parts (Evidence) / 部品（根拠の置き場）

> 方針: spec.md は「結論（採用品/方針）」、parts.md は「証拠（根拠表/一次ソース/購入リンク/代替）」。
> 在庫やURLは変動するので `parts.md` を正とし、`spec.md` には「参照先」だけを書く。

- 最終更新: 2026-02-08
- 管理: GitHub Issue を変更履歴に残す（例: `[W2-01]`）

## 1. 採用部品一覧（MPN / 役割 / 一次ソース / 購入リンク）

| 区分 | 採用品（MPN / 型番） | 役割 | 一次ソース（データシート等） | 購入リンク（参考） | 備考 |
|---|---|---|---|---|---|
| MCUボード | Raspberry Pi Pico (RP2040) | W2の実機Bring-up、W3以降はヘッダ互換で載せ替え想定 | RP2040 Datasheet（I/O絶対最大・VIH/VILの根拠） | [Amazon](https://www.amazon.co.jp/dp/B09229YRR4) | Pico（RP2040）前提 |
| Optical Tx | Everlight PLT133/T10W | POF光送信（TOSLINK系） | データシート（VCC/入力レベル/絶対最大/推奨回路） | [マルツ](https://www.marutsu.co.jp/pc/i/41237282/) | W2は3.3V動作で使用 |
| Optical Rx | Everlight PLR237/T10BK | POF光受信（TOSLINK系） | データシート（VCC/出力レベル/推奨回路） | [マルツ](https://www.marutsu.co.jp/pc/i/13672939/) | W2は3.3V動作で使用 |
| POFファイバ | TOSLINK 光デジタルケーブル 1.0m | Tx–Rxの接続（W2疎通確認） | 規格はTOSLINK/POF想定 | [Amazon（購入品）](https://www.amazon.co.jp/dp/B00L3KO5WK) | “オーディオ用”でOK（まず動かす） |
| 電源（W3以降） | Bourns MF-MSMF050-2 | VBUS(5V)の過電流保護（リセッタブルヒューズ） | Bourns datasheet（PPTC） | [マルツ](https://www.marutsu.co.jp/pc/i/15854119/) | 初期候補: Ihold 0.5A / Itrip 1A / 1812 |
| 電源（W3以降） | Littelfuse SMAJ5.0A（Unidirectional） | VBUS(5V)のサージ/ESD保護（TVS） | Littelfuse datasheet（SMAJシリーズ） | [マルツ](https://www.marutsu.co.jp/pc/i/1669108/) | 初期候補: Vrwm 5V（VBUS→GNDへ） |
| 電源（W3以降） | Diodes Inc AP2112K-3.3TRG1 | VBUS(5V)→3.3V 生成（LDO） | Diodes Inc datasheet（AP2112K） | [マルツ](https://www.marutsu.co.jp/pc/i/1804613/) | 初期候補: 0.6A / SOT-23-5。W2はPicoの3V3(OUT)給電、W3から基板で正式化 |

### 1.1 採用理由（入手性メモ）
- PLT133/PLR237 を採用した理由: 購入可能な候補が実質これに収束したため（入手性優先）。

## 2. 整合説明（電源電圧とI/Oレベル）

前提: 信号レベルは 3.3V系（RP2040 IOVDD=3.3V）で統一する。

### 2.1 RP2040（Pico側）の入力条件（根拠）
- 入力 High 判定（IOVDD=3.3V）: VIH(min)=2.0V
- 入力 Low 判定（IOVDD=3.3V）: VIL(max)=0.8V
- 絶対最大（Digital IO）: VPIN <= IOVDD + 0.5V（= 3.3 + 0.5 = 3.8V 目安）
  → 3.3V系以外（5V等）を直結しない
- 出典: RP2040 datasheet（Absolute Max / IO Electrical Characteristics）
- データシート: https://pip-assets.raspberrypi.com/categories/814-rp2040/documents/RP-008371-DS-1-rp2040-datasheet.pdf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

### 2.2 PLT133（Tx入力）← RP2040 GPIO 出力の整合
- PLT133 入力条件: Vih(min)=2.0V, Vil(max)=0.8V
- PLT133 絶対最大: Vin <= Vcc + 0.5V
- したがって、RP2040の 0/3.3V GPIO は PLT133 の入力条件を満たし、かつ絶対最大も超えない（Vcc=3.3V運用）。

### 2.3 PLR237（Rx出力）→ RP2040 GPIO 入力の整合
- PLR237 出力条件（Rev.1）: VOH(min)=Vcc-0.4V（@3.3V時 2.9V）, VOL(max)=0.5V
- したがって、VOH(2.9V) > RP2040 VIH(min)(2.0V)、VOL(0.5V) < RP2040 VIL(max)(0.8V) となり、3.3V系で論理整合が取れる。

## 3. 根拠表（データシート抜粋）

### 3.1 Everlight PLT133/T10W（Tx）

> 設計メモ
> - データシートは「推奨動作（Recommended）」と「絶対最大（Absolute Max）」を2段階で扱う。推奨内で設計し、絶対最大は踏まない。
> - Vcc/Vin は平均ではなく最悪値（min/max）で判断する。特に電源OFF中にVinが入る（逆給電）が事故りやすい。

| 分類 | パラメータ | MIN | TYP | MAX | 単位 | 設計での意味（チェック観点） |
|---|---:|---:|---:|---:|---|---|
| 推奨動作 | Vcc（Supply Voltage） | 2.7 | 3.0 | 5.50 | V | 3.3V系で動作可。電源リップル/瞬断を含めて 2.7–5.5V に収める。 |
| 入力（TTL） | Vih（High判定） | 2.0 | - | - | V | 駆動元GPIOのHighが2.0V以上であること（3.3V GPIOならOK）。 |
| 入力（TTL） | Vil（Low判定） | - | - | 0.8 | V | 駆動元GPIOのLowが0.8V以下であること（0VならOK）。 |
| 消費（電源） | Icc（Dissipation current） | - | 2.0 | 4.0 | mA | Max 4.0mA。W2のPico 3V3(OUT)給電では外部負荷を増やしすぎない（要確認）。 |
| 絶対最大 | Vcc | -0.5 | - | 7 | V | Vcc > 7V は破損リスク。電源過渡（挿抜/スパイク）も含めて踏まない。 |
| 絶対最大 | Vin（DC input） | -0.5 | - | Vcc+0.5 | V | Vin > Vcc+0.5V は破損リスク（Vcc OFF中のGPIO Highなど）。Vin < -0.5V も破損リスク。 |
| 推奨回路 | デカップリング | 0.1 | - | - | µF | 最低0.1µF をVcc–GND間に実装。部品近傍（目安: 7mm以内）。 |
| 注意事項 | 電源OFF時の条件 | - | - | - | - | 電源OFF時は Vin と Vcc を一緒に切る（逆給電防止）。 |
| 注意事項 | 入力未定義（FLOAT） | - | - | - | - | Vin=FLOATINGでLEDがONになり得る。起動直後/リセット中にVinを浮かせない（FWでLow、回路でプルダウン）。 |

壊れる条件（要点）
- Vin が Vcc+0.5V を超える（例: Vcc OFF中にGPIO High、5V信号直結）
- Vin が -0.5V 未満になる（負電圧・リンギング）
- Vcc が 7V を超える（電源スパイク含む）

- 一次ソース: Everlight PLT133/T10W datasheet（Rev.5）

### 3.2 Everlight PLR237/T10BK（Rx）

| 分類 | パラメータ | MIN | TYP | MAX | 単位 | 設計での意味（チェック観点） |
|---|---:|---:|---:|---:|---|---|
| 推奨動作 | Vcc（Supply Voltage） | 3.0 | - | 5.50 | V | 3.3V動作OK（Min 3.0V）。 |
| 出力（TTL） | VOH（High出力） | Vcc-0.4 | - | - | V | Vcc=3.3V時、Min 2.9V。RP2040 VIH(2.0V)に対しマージンあり。 |
| 出力（TTL） | VOL（Low出力） | - | 0.4 | 0.5 | V | Max 0.5V。RP2040 VIL(0.8V)に対しマージンあり。 |
| 消費（電源） | Icc（Dissipation current） | - | 2.0 | 4.0 | mA | Max 4.0mA。 |
| 絶対最大 | Vcc | -0.5 | - | 5.5 | V | Vcc > 5.5V で破損リスク（Txより耐圧が低い点に注意）。 |
| 絶対最大 | Vout | - | - | Vcc+0.3 | V | Vout > Vcc+0.3V で破損リスク。出力ピンへの過電圧印加禁止。 |
| 推奨回路 | バイパスコンデンサ | 0.1 | - | - | µF | 必須。部品近傍（7mm以内）に配置。 |
| 注意事項 | 半田付け温度 | - | - | 260 | °C | 260°C以下、10秒以内。 |

- データシート: https://mm.digikey.com/Volume0/opasdata/d220001/medias/docus/5335/PLR237-T10BK_Rev1_3-30-21.pdf

### 3.3 RP2040（参考: I/O絶対最大 & 入力閾値）
- データシート: https://datasheets.raspberrypi.com/rp2040/rp2040-datasheet.pdf
- 参照箇所（目安）: Pin Specifications（Absolute Maximum Ratings / IO Electrical Characteristics）

## 4. 代替候補（バックアップ）: TOTX/TORX

目的: 採用品（PLT/PLR）を揺らさずに、調達停止リスクを下げる保険を置く。

| セット | 候補 | 想定VCC | 使うときの注意 | 一次ソース |
|---|---|---:|---|---|
| 3.3V系 | TOTX147AL (Tx) / TORX147L (Rx) | 3.3V系 | I/O整合（VOH/VOL/VIH/VIL）を再確認。フットプリント/ピン配置も再確認。 | メーカ/代理店データシート（後でURL追記） |
| 5V系 | TOTX173 (Tx) / TORX173 (Rx) | 5V系 | RP2040は5V直結不可。レベル変換や抵抗/トランジスタが必要になる可能性。 | （例）Mouser掲載のToshibaデータシート |

- 5V系 参考（Mouser）: https://www.mouser.com/datasheet/2/408/totx173_torx173-1181045.pdf

## 5. 電源保護・LDO候補（W3用）

初期候補（採用案）
- Polyfuse: Bourns MF-MSMF050-2（1812, Ihold 0.5A / Itrip 1A / 15V）  
  - マルツ: https://www.marutsu.co.jp/pc/i/15854119/
- TVS: Littelfuse SMAJ5.0A（5V Vrwm, Unidirectional, DO-214AC）  
  - マルツ: https://www.marutsu.co.jp/pc/i/1669108/
- LDO: Diodes Inc AP2112K-3.3TRG1（3.3V固定, 0.6A, SOT-23-5）  
  - マルツ: https://www.marutsu.co.jp/pc/i/1804613/

選定時に見る観点（メモ）
- VBUS入力（5V）での定格、逆接/サージ保護（TVSのVrwm/クランプ、許容パルス）
- LDOの dropout、最大電流、発熱（θJA）、PSRR、推奨コンデンサ条件
- プレースホルダ運用なら、ネットを先に固定（VBUS_IN / +3V3 / GND / 任意: LDO_EN）して後で型番差し替え

## 6. 変更履歴（Issueトレーサビリティ）
- 2026-01-10: 初版作成（W2-01）
- 2026-02-08: 電源部品（Polyfuse/TVS/LDO）の初期候補とマルツリンクを追記。

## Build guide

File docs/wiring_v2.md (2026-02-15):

# wiring_v2.md — 配線（本番用）: USB VBUS(5V) → 保護 → LDO → +3V3 → MCU/Tx/Rx

## ネット（固定）
電源系
- VBUS_IN: USBコネクタのVBUS(5V)
- VBUS_PRO: Polyfuse後、LDO手前の5V
- +3V3: LDO出力の3.3V配布
- GND: 全体GND（USBのGNDと同一）
- LDO_EN: LDO enable（任意。作るなら名前固定）
- 注記: `VBUS_PROT` は旧表記。正規名は `VBUS_PRO`。

信号系（例）
- GP_TX: MCU→Tx入力
- GP_RX: Rx出力→MCU入力

期待電圧（テスター）
- VBUS_IN: 約5V
- VBUS_PRO: 約5V
- +3V3: 約3.3V

## 全体配線（ブロック）
    USBコネクタ
      |
      |  VBUS_IN
      +-----> TVS: VBUS_IN → GND
      |
      +-----> Polyfuse(直列): VBUS_IN → VBUS_PRO → LDO(IN)
                                         LDO(OUT) → +3V3配布
                                         LDO(GND) → GND
                                         LDO(EN)  → LDO_EN（任意）

    +3V3配布 → MCU +3V3入力
    GND      → MCU GND

    +3V3配布 → Tx Vcc
    GND      → Tx GND
    GP_TX    → Tx Vin

    +3V3配布 → Rx Vcc
    GND      → Rx GND
    Rx Vout  → GP_RX

    Tx（光） → POF → Rx（光）

## 配置ルール（実装のコツ）
- TVSはUSBコネクタ直近（VBUS_INとGNDへの経路を短く太く）
- Polyfuseはコネクタ直後〜LDO手前（VBUS_IN直列）
- LDOは負荷（3.3Vを使う回路）に近め
- LDOの入力/出力コンデンサはLDOの足元に置く
- GNDは1系統に統一（別GND名を増やさない）

## 部品の接続（回路図でやること）
USBコネクタ
- VBUSピン → VBUS_IN
- GNDピン → GND

TVS（プレースホルダ）
- 片側 → VBUS_IN
- 片側 → GND

Polyfuse（プレースホルダ）
- 直列で挿入: VBUS_IN → VBUS_PRO

LDO（プレースホルダ）
- IN  → VBUS_PRO
- OUT → +3V3
- GND → GND
- EN  → LDO_EN（任意。使わないなら既知レベル固定、またはEN無し品を採用）

コンデンサ（推奨。プレースホルダで席確保）
- C_IN: VBUS_PRO ↔ GND（LDO近接）
- C_OUT: +3V3 ↔ GND（LDO近接）
- Tx/Rxそれぞれ: Vcc ↔ GND に0.1uFを近接

MCU（例: Pico互換ヘッダ）
- MCU 3.3Vピン → +3V3
- MCU GNDピン → GND
- MCU GPIO → GP_TX / GP_RX

Tx（PLT133）
- Vcc → +3V3
- GND → GND
- Vin → GP_TX

Rx（PLR237）
- Vcc → +3V3
- GND → GND
- Vout → GP_RX

## テストポイント（推奨）
- TP_GND: GND
- TP_VBUS_IN: VBUS_IN
- TP_VBUS_PRO: VBUS_PRO
- TP_3V3: +3V3
- TP_TX: GP_TX（任意）
- TP_RX: GP_RX（任意）

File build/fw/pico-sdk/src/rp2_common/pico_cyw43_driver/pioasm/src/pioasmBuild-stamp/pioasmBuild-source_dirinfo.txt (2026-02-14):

# This is a generated file and its contents are an internal implementation detail.
# The download step will be re-executed if anything in this file changes.
# No other meaning or use of this file is supported.

method=source_dir
command=
source_dir=C:/Users/tyosu/Desktop/optical-modem-ish/external/pico-sdk/tools/pioasm
work_dir=

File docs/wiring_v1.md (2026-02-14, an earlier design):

# wiring_v1.md — W2 暫定配線（Pico + PLT133/PLR237 + 1m POF）

## Why（目的）
- 最小構成で光リンクが動くかどうかの動作確認（W3以降の基板設計を迷わせない）
- 詰まる可能性があるポイント（向き/ピン取り/測り方/安全）も前もって 詳細手順化し再現可能 にする

## What（やること）
- Raspberry Pi Pico（RP2040）と Everlight PLT133/T10W（Tx）、PLR237/T10BK（Rx） をブレッドボード配線
- PicoのGPIOでTx入力をトグルし、Rx出力の変化を確認
- W2はPicoの3V3(OUT)給電で固定（W3以降は VBUS→保護→LDO→3.3V に移行予定）

### 3V3(OUT) 取り扱いメモ（W2暫定）
- W2はPico 3V3(OUT)から給電するが、mA級の小負荷に限定し、過剰負荷は禁止。
- 根拠：PLT133 Icc=MAX 10mA、PLR237 Icc=MAX 4mA（データシート参照。リンクは parts.md に集約）。
- NG例：モータ／リレー／ヒータ／高輝度LED／大量LED 等の大電流負荷は接続しない。
- 目安：Pico datasheet では 3V3 ピンの外部負荷は 300mA未満推奨（断定せず“推奨”として扱う）。 
  
## Done（受け入れ条件 / Acceptance Criteria）
- [ ] 配線が「電源→信号→光」の順に安全に組めた（ショート/逆接の未然防止ができた）
- [ ] Txトグルに対してRx出力が変化する（LED/テスター/ロジアナのいずれかで確認）
- [ ] 失敗時の切り分け（向き/配線/電源/設定/ファイバ）がこのドキュメントだけで進められる

## Notes（調査メモ / 参考）
- PLT133（Tx）ピン：1=Vin, 2=Vcc, 3=GND（ピン機能表に明記）
- PLR237（Rx）：データシート図中の表記では3端子が Vcc / GND / Vout として示される（測定回路/アプリ回路図）。ピン番号は「足を下、光コネクタを上、正面から見て左→右が1→2→3」の一般的な読み方で扱い、左=Vcc、中央=GND、右=Vout として配線する（不安な場合はデータシートのパッケージ寸法図と図中表記を突合）。
- Rx（PLR237 Vout）は Pico内蔵プルダウン で対応（外付け抵抗は無し）。
- オシロなし前提：まずは LED/テスター/ロジアナ で「変化がある」事実を取る。

---

## 0. 使うもの（W2）
- MCU：Raspberry Pi Pico（RP2040）
- Tx：Everlight PLT133/T10W
- Rx：Everlight PLR237/T10BK
- POF：TOSLINK互換 1m 光デジタル（POF）
- ブレッドボード、ジャンパ線
- （推奨）テスター、（あれば）ロジックアナライザ、（任意）LED+抵抗
- デカップリング：0.1uF（Tx/Rx 各1個）

---

## 1. 重要な前提（安全・壊さない）
1) 必ず電源OFFで配線する（電源ONのまま抜き差ししない）
2) VccとGND逆は即死：まずテスターでショートが無いことを確認
3) 電圧は3.3Vで統一：W2はPicoの3V3(OUT)のみ使う（VBUS直結はしない）
4) デカップリングは必須：Rxデータシートでは 0.1uF をVcc-GNDに近接配置する例が示され、C1/C2は 7mm以内配置が推奨されている（基板化するW3では特に重要）

---

## 2. 配線の全体像（ブロック図）

```
(USB)             (W2: Pico内蔵3.3V)
PC ─USB─> Pico ──3V3(OUT)─────────────┬─────────> PLT133 Vcc (Pin2)
               GND ───────────────────┼─────────> PLT133 GND (Pin3)
               GP2 (Tx Data)──────────┴─────────> PLT133 Vin (Pin1)

Pico 3V3(OUT)─────────────────────────┬─────────> PLR237 Vcc (左ピン)
Pico GND ─────────────────────────────┼─────────> PLR237 GND (中央ピン)
Pico GP3 (Rx Data In) <────────────────┴─────────> PLR237 Vout (右ピン)

PLT133（Tx）──(POF 1m)──> PLR237（Rx）
```

- GPIO割り当て（暫定）
  - Tx入力：Pico GP2 → PLT133 Vin
  - Rx出力：PLR237 Vout → Pico GP3

---

## 3. 部品ごとのピン取り（向き・番号）

### 3.1 PLT133/T10W（Tx）
- Pin1 = Vin（入力）
- Pin2 = Vcc（3.3V）
- Pin3 = GND

向きの考え方（初心者向け）
- まず「データシートのピン番号が振られた図」と「ピン機能表（1/2/3）」をセットで見る
- ブレッドボードでは、Pin2に3.3V、Pin3にGND を入れてから Pin1にGPIO を入れる（順番が安全）

### 3.2 PLR237/T10BK（Rx）
- データシートの測定/アプリ回路図では、3端子が Vcc / GND / Vout として示される
- W2では配線ミスを避けるため、以下の 見た目基準 で固定する：
  - 足を下、光コネクタを上、正面（光差し込み側）から見て
  - 左=Vcc、中央=GND、右=Vout

### 3.3 ピン配置（簡易ASCII図）
#### PLT133/T10W（Tx）※足を下、正面（光差し込み側）から見たイメージ
┌─────────┐
│ [光] │
└─────────┘
1 2 3
Vin Vcc GND

#### PLR237/T10BK（Rx）※足を下、光コネクタを上、正面から見たイメージ
┌─────────┐
│ [光] │
└─────────┘
左 中 右
Vcc GND Vout

---

## 4. 具体配線（手順）

### 4.1 電源（先にここだけ完成させる）
1. PicoをUSBにつながず、ブレッドボードに置く
2. Pico 3V3(OUT) → ブレッドボード3.3Vレール
3. Pico GND → ブレッドボードGNDレール
4. テスターで 3.3VレールとGNDがショートしてない ことを確認

### 4.2 Tx（PLT133）
1. PLT133 Pin2(Vcc) → 3.3V
2. PLT133 Pin3(GND) → GND
3. PLT133 Pin1(Vin) → Pico GP2
4. 0.1uF を PLT133 の Vcc-GND 間に近接（足元でOK）

### 4.3 Rx（PLR237）
1. PLR237 Vcc(左) → 3.3V
2. PLR237 GND(中央) → GND
3. PLR237 Vout(右) → Pico GP3
4. 0.1uF を PLR237 の Vcc-GND 間に近接
5. Picoの GP3 に内蔵プルダウン を有効化（後述）

### 4.4 ブレッドボード版テストポイント（TP）
> ブレッドボード上に「分岐点」を作って測定点にする。

- TP_GND：GNDレール上の任意の穴（ここにプローブのGNDクリップを固定）
- TP_3V3：3.3Vレール上の任意の穴（電圧確認用）
- TP_TX：GP2 → PLT133 Vin の途中に「分岐列」を作る  
  - 配線：GP2 → (TP_TX列) → PLT133 Vin
  - 測定：TP_TX列の“測定用ピン”にロジアナ/オシロを当てる
- TP_RX：PLR237 Vout → GP3 の途中に「分岐列」を作る  
  - 配線：PLR237 Vout → (TP_RX列) → GP3
  - 測定：TP_RX列の“測定用ピン”にロジアナ/オシロを当てる

### 4.4 光（POF）
- PLT133（Tx）→ PLR237（Rx）へ POFを接続
- まずは「抜けにくい/曲げすぎない/コネクタ奥まで刺さる」を確認

---

## 5. 動作確認（オシロなし想定）

### 5.1 最小の確認ステップ（おすすめ順）
1) 電圧確認
- PicoをUSB給電し、3V3レールが 約3.3V になっている

2) GPIOが動いている確認（Tx側）
- GP2 を 1Hz〜10Hz でON/OFFトグル（LEDでも見える）

3) Rxが変化する確認
- GP3 の入力を読み、シリアルログに出す（0/1が切り替わるか）
- または GP3 にLED（+抵抗）をつないで点滅を見る（ただし極性と電流に注意）

### 5.2 Pico側の最小コード（例：Arduino-Pico / pico-sdk どちらでも可）
- 要点は2つだけ：
  - GP2 = 出力でトグル
  - GP3 = 入力 + PULLDOWN

（実装言語/環境はW1〜の方針に合わせる。ここではロジックのみ）

---

## 6. 期待結果（OK/NGの見分け方）

### OK
- GP2をトグルすると、GP3が同じタイミングで 0/1 変化する
- 低速（数Hz〜数kHz）でもまず反応が取れる

### よくあるNGと切り分け
1) GP3がずっと0/ずっと1
- ファイバ未接続、向き違い、Rx電源未供給、Rxピン取り間違い

2) GP2は動いているがGP3が変化しない
- TxのVin/Vcc/GNDの取り違え（Pin1/2/3）
- RxのVcc/GND/Voutの取り違え（左/中/右）

3) 不安定（揺れる/ノイズっぽい）
- デカップリング不足（0.1uFが遠い/無い）
- GNDが細く長い、配線がぐちゃぐちゃ（まず短く整理）

4) プルダウン無し（FLOAT）っぽい
- 症状：GP3がランダムに0/1で揺れる／触ると変わる／ファイバ未接続でも値が安定しない
- 対処：GP3を 入力 + PULLDOWN に設定（または外付けで10k〜100kをGNDへ）

5) 電源不足（3V3ドロップ）
- 症状：3V3が3.3V付近にならない／動いたり動かなかったり不安定／Rxが全く切り替わらない
- 対処：3V3(OUT)を再測定、USBケーブル/ポート変更、配線短縮、0.1uFをTx/Rx近くに追加

---

## 7. W2とW3の違い（混乱ポイントを先に潰す）
- W2（この配線）：Picoの 3V3(OUT) を使って、最短で動くかどうかの確認を行う。
- W3（基板）：USBの VBUS(5V) を入力として、
  - Polyfuse（過電流）
  - TVS（サージ/ESD）
  - LDO（5V→3.3V安定化）
  の「評価ボードっぽい正しい型」にする

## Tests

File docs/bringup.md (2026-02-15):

# Bring-up Procedure

## 目的
最低構成で「電気→光→電気」が成立した証拠（波形/写真/条件）と、初見でも30分で再現できる手順を残す（W3以降の設計判断を安定させる）。

---

## 0. 事前準備（共通）
### 0.1 必要機材
- マルチメータ（必須）
- ロジアナ（推奨。PulseView / Saleae Logic 等）
- PC（Thonny）

### 0.2 事前確認
- 部品の向き（Tx/Rx、TOSLINKの向き、ファイバの向き）
- ジャンパ線の刺さり（ブレッドボードが原因で接触不良が起きやすい）
- GND共有が取れていること（最優先）

---

## 1. 配線（最低構成）
### 1.1 Pico ↔ Tx/Rx（必須）
- 電源：Pico 3V3(OUT) → Tx VCC / Rx VCC（3.3Vレール扱い）
- GND：Pico GND → Tx GND / Rx GND（共通GND）
- 送信：Pico GP2 → Tx Vin
- 受信：Rx Vout → Pico GP3

補足
- プルダウン抵抗（例：220kΩ）は今回の構成では不要だった。入れるとGP3が常時0になり受信できない場合がある。

### 1.2 記録（必須）
- Photo: wiring_overview.jpg
- メモ：
  - ファイバ長：1 m
  - プル抵抗：なし（今回）
  - 電源：Pico 3V3(OUT)
  - 測定点：GP2 / GP3 / 3.3V

---

## 2. Phase 1: Power（電源）
### 2.1 通電前チェック（PCB本線）
- [ ] 目視でショート/ブリッジがない（J1/F1/U1 周辺を優先）
- [ ] TP1/TP2/TP3/TP4 の位置を確認し、測定点を取り違えない
- [ ] VBUS_IN - GND、+3V3 - GND の短絡疑いがないことを確認する

### 2.2 適用範囲（PCB本線）
- 本線の電源判定は `2.3 PCB（USB→LDO→+3V3）電源Bring-up` を使う
- Pico 3V3 給電のブレッドボード手順は本線から分離し、`付録A` に記載する

### 2.3 PCB（USB→LDO→+3V3）電源Bring-up（テスターのみ）
事前チェック（通電前）
- 短絡確認: +3V3-GND（必要なら VBUS_IN-GND も）で短絡疑いがないことを確認する
- 極性確認: 部品向き（電解/ダイオード/TVS/LDO向き）を確認する
- 目視確認: はんだブリッジ、未はんだ、浮き部品がないことを確認する

電源投入条件（デフォルト）
- 給電元は PC 直結 USB（ハブ無し）を標準とする
- ケーブル条件は固定しない（種別 A-C/A-A、長さ目測、識別メモを記録に必須で残す）
- 外部負荷条件は 2 段階で判定する
  - (A) 基板単体
  - (B) Pico + Tx/Rx 接続後
- 室温 20-30℃ を前提とし、範囲外なら記録に残す

測定条件
- DMM は DC 電圧、オートレンジで可
- 計測器例: AstroAI DM6000AR（6000 count）または同等以上
- 仕様値（自動レンジ DCV 6V）: 分解能 1mV、精度 ±(0.8% + 3dgt)
- 精度の前提条件: メーカー仕様の基準温度（例: 23℃±5℃）から外れる場合は誤差増加を見込む
- 3.3V測定時の誤差目安: ±(3.3*0.008 + 0.003) ≒ ±0.029V（約±0.03V）
- 上記の計測誤差は PASS-B の+3V3レンジ確定時に反映する
- 黒リードを TP2（TP_GND）に当て続ける（基準点）
- 赤リードで各 TP を測る

測定手順（時系列）
1. 基板単体（A）で通電し、T+0-2 秒で TP1/TP4 を測る（致命的短絡・誤配線の早期検知）
2. 基板単体（A）で T+10 秒に TP1/TP4/TP3 を測る（初期過渡を避けた定常値を記録）
3. 任意で T+60 秒に TP1/TP4/TP3 を再測定する（軽い安定性/温度ドリフト確認）
4. Pico + Tx/Rx 接続後（B）に同手順を実施し、起動 10 秒後の TP1/TP4/TP3 を記録する（起動直後の過渡回避）
5. 任意で起動 60 秒後も再測定する（負荷時のドリフト確認）

| TP名 | 正規ネット名 | 測定場所の特定（TP or 部品参照名） | 期待値レンジ | 判定基準 |
| --- | --- | --- | --- | --- |
| TP2（TP_GND） | GND | TP2（なければ GND テストパッド） | 0 V | 0 V から大きく外れる場合は GND 参照不良として FAIL |
| TP1（TP_VBUS） | VBUS_IN | TP1（なければ J1 の VBUS 側） | PASS-A/PASS-B: 4.75-5.25 V | 範囲内なら OK（USB 5V 入力として妥当） |
| TP4（TP_VBUS_PRO） | VBUS_PRO | TP4（なければ F1 二次側または U1 IN ノード） | PASS-A/PASS-B: 4.75-5.25 V | 範囲内なら OK（保護後 5V として妥当） |
| TP3（TP_3V3） | +3V3 | TP3（なければ U1 OUT / C_OUT1 と同ノード） | PASS-A（暫定）: 3.0-3.6 V / PASS-B: TODO（未確定） | 暫定危険域は下記「TP3危険域判定」を優先。閾値は暫定 |

注記
- VBUS の 4.75-5.25 V は USB 2.0 の一般的な VBUS 許容範囲を根拠にした判定
- +3V3 の危険域閾値は PASS-A 用の暫定値であり、LDO 確定後に更新する

TP3（+3V3）危険域判定（PASS-A用・暫定）
- `+3V3` >= 3.8 V: 即停止（電源を抜く）
- 3.6 V <= `+3V3` < 3.8 V: 停止して原因調査（継続しない）
- `+3V3` < 0.2 V: FAIL（未供給 or 短絡疑い）
- 0.2 V <= `+3V3` < 2.7 V: FAIL（+3V3系として成立していない）
- 2.7 V <= `+3V3` < 3.0 V: FAIL（境界域。運用としては落とす）
- 3.0 V <= `+3V3` <= 3.6 V: PASS-A候補（安全域としてはOK）

合否基準（2段階）
- PASS-A（Safety Pass）: TP1/TP4 が 4.75-5.25 V かつ TP3 が「3.0-3.6 V」の暫定安全域にある
- PASS-B（Spec Pass）: 未確定/TODO。PASS-A を満たし、かつ確定済み +3V3 仕様レンジに入ること

PASS-B（Spec Pass）未確定理由
- LDO 型番が最終確定していない
- LDO の出力精度、温度特性、ライン/ロードレギュレーション条件が未確定
- 負荷条件（基板単体 / Pico + Tx/Rx 接続）ごとの仕様判定条件が未確定
- 既知の参考値として Tx/Rx の消費電流は `docs/parts.md` に Icc(max)=4.0mA と記載があるが、PASS-B 判定に必要な全体負荷条件は未確定

未確定事項リスト（PASS-B確定のためのTODO）
- +3V3 の PASS-B 期待レンジ未確定
  - 必要情報: 採用LDO最終型番、固定出力値、許容差、推奨コンデンサ条件
- PASS-B の温度条件未確定
  - 必要情報: 仕様レンジを定義する最低/最高温度と測定条件
- 負荷条件別の最大電流見積もり未確定（基板単体 / Pico+TxRx）
  - 必要情報: 搭載部品構成、Pico/Tx/Rxの動作モード別電流（起動直後・定常・ピーク）
- PASS-B 判定ルール未確定
  - 必要情報: 上記条件 + 計測器誤差（DMM精度）を反映した+3V3の最小/最大レンジと合否基準

NG 切り分け（TP1 → TP4 → TP3）
- TP1 が NG（VBUS_IN 不在/低すぎ/高すぎ）: ケーブル不良、USB ポート側制限、ハブ経由、J1 はんだ不良を疑う。ケーブル/ポートを変えて再測定し、変更内容を記録する
- TP1 が OK で TP4 が NG: F1（Polyfuse）周り（はんだ不良、部品不良、トレース断/短絡）を疑う。F1 前後ノードの導通と電圧差を確認する
- TP4 が OK で TP3 が NG: LDO（U1）周り（向き、はんだ、短絡、入出力コンデンサ）を疑う。U1 IN/OUT と GND 間の電圧を順に確認する
- TP3 が 3.6 V 以上の場合: 即停止または停止調査の条件に従い、原因が特定できるまで再通電しない
- ケーブル/USB ポート差は常に疑い候補として扱い、給電条件ログとひも付けて比較する

記録テンプレート（コピペして使用）
```md
- 日付(YYYY-MM-DD):
- 基板Rev（無いなら識別子）:
- 構成（ジャンパ/0Ω実装状態、Pico接続有無、TxRx接続有無）:
- 給電元（PC直結USB、ポート種別、ハブ有無）:
- ケーブル（種別A-C/A-A、長さ目測、識別メモ）:
- 計測器（DMM機種、レンジ=オート）:
- 環境（室温、20-30℃外ならその値）:
- 実測値（A: 基板単体）:
  - T+0-2s: TP1= , TP4=
  - T+10s: TP1= , TP4= , TP3=
  - T+60s(任意): TP1= , TP4= , TP3=
- 実測値（B: Pico+TxRx接続後）:
  - 起動10s: TP1= , TP4= , TP3=
  - 起動60s(任意): TP1= , TP4= , TP3=
- 判定（PASS-A / PASS-B / FAIL / STOP）:
- STOP時理由（該当時）:
- 写真リンク（配線と測定位置が分かるもの）:
```

---

## 3. Phase 2: MCU（Pico動作）
- [×] ThonnyでMicroPythonが実行できる（printが出る）
- [×] 使用GPIOが衝突していない（GP2/GP3/GP26など）

---

## 4. Phase 3: GPIO（電気の成立）
### 4.1 Tx（GP2）が出ていること
- [×] GP2を低速でトグル/PWMできる（最初は50Hz）

### 4.2 Rx（GP3）が読めること
- [×] GP3が入力として 0/1 を読み取れる

補足
- 受信が疑わしい場合は一度 Rx Vout を GP26(ADC) に繋いで、ON/OFFで電圧差が出るかを確認する（アナログ確認）。

---

## 5. Phase 4: Optical Link（電気→光→電気の成立）
### 5.1 FW（MicroPython / エッジカウント）
- GP2: PWM出力
- GP3: IRQ（RISING|FALLING）でエッジ数をカウント

期待値
- 50Hz → 100 edges/sec
- 100Hz → 200 edges/sec
- 200Hz → 400 edges/sec
- 400Hz → 800 edges/sec
- 500Hz → 1000 edges/sec

### 5.2 証拠（必須）
- ロジアナで GP2（Tx入力）と GP3（Rx出力）を同時観測し、スクショを残す
  - D0 = GP2
  - D1 = GP3

取得推奨
- OK例：100Hz（安定）
- OK例：200Hz（安定）
- 限界例：400Hz or 500Hz（マージン低下の例）

100Hz
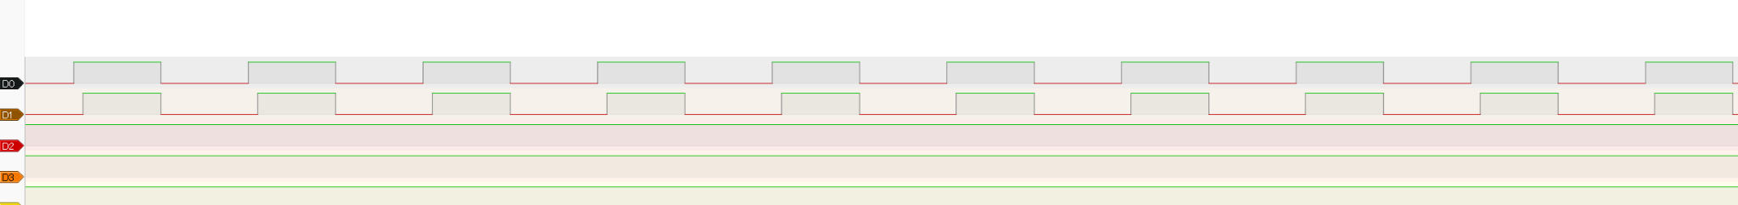
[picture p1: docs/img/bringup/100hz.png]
100Hz


200Hz
200Hz

400Hz
400Hz

500Hz
500Hz
---

## 6. よくある失敗（NG集 / チェックリスト）
- 向き違い（Tx/Rx、ファイバ方向）
- GND共有が取れていない
- ブレッドボード接触不良（刺さりが浅い/同一列ミス）
- プルダウン抵抗で受信が潰れる（今回：220kΩでGP3が常時0になる）
- Tx側の配線不良（GP2→Tx Vin が外れている/刺さっていない）

---

## 付録A ブレッドボード暫定手順（将来廃止予定）
注意
- 本線は 2.3 PCB（USB→LDO→+3V3）電源Bring-up。これは暫定で、将来廃止予定。
- PCB手順のTP/判定と混同しないこと（必要なら別表）。

対象
- W2 相当のブレッドボード構成で、Pico 3V3(OUT) から Tx/Rx に給電する暫定確認のみ
- この付録の判定は 2.3 の PASS-A/PASS-B とは別管理

手順（暫定）
- Pico 3V3(OUT)（3.3Vレール）測定
- Tx VCC 測定
- Rx VCC 測定

測り方（暫定）
- 黒プローブ：Pico GND
- 赤プローブ：3.3Vレール（または Tx/Rx の VCC ピン）

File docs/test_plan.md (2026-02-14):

# Test Plan

## 目的
通信リンクの品質（BER/PER）と機能（同期/再送/モード切替）を、**条件・合否基準・ログ**まで含めて再現可能に試験する。

---

## 1. テスト条件（マトリクス：別ファイル推奨）
- Vcc: 3.0 / 3.3 / 3.6 V（予定）
- rate: 0.5 / 1 / 2 Mbps
- mode: A / B
- power: 0 / 1 / 2
- cable: short / long

> 実体：`docs/test_matrix.csv`（後で追加）

---

## 2. 試験ID一覧（ヘッダだけ：W1テンプレ）
| Test ID | Category | Purpose | Setup | Procedure | Expected Result | Pass/Fail Criteria | Log Output | Notes |
|---|---|---|---|---|---|---|---|---|
| TP-001 | Power |  |  |  |  |  |  |  |
| TP-002 | Bring-up |  |  |  |  |  |  |  |
| TL-001 | Link |  |  |  |  |  |  |  |
| TM-001 | Mode |  |  |  |  |  |  |  |
| TQ-001 | Quality(PER) |  |  |  |  |  |  |  |
| TQ-002 | Quality(BER) |  |  |  |  |  |  |  |

---

## 3. 合否基準（仮置き）
- PER: TBD（例：< 1e-3）
- BER: TBD（例：< 1e-6）
- 連続運転：TBD（例：10分無停止）

---

## 4. ログ
- Format: `docs/log_format.md` に従う
- 保存先: `logs/`（後で命名規則を確定）

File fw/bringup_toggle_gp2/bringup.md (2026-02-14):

# FWのビルド/書き込み手順（MicroPython / Pico）

ファイル名：docs/fw_bringup_toggle_gp2.md

## 対象FW
- `fw/bringup_toggle_gp2/main.py`（GP2送信 / GP3受信の確認用）

## 手順（Thonny）
1. Raspberry Pi Pico をUSB接続する
2. Thonnyを起動し、Interpreter を `MicroPython (Raspberry Pi Pico)` に設定する
3. `fw/bringup_toggle_gp2/main.py` を開く
4. `Save` → 保存先に `Raspberry Pi Pico` を選び、ファイル名を `main.py` として保存する
5. `Run`（▶）で実行する

## 実行確認（最小）
- シリアル出力（ThonnyのShell）に `edges_per_sec` が表示される
- 50/100/200/500Hzで期待値近傍（100/200/400/1000）が出ることを確認する

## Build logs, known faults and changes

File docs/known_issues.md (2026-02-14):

# Known Issues

## 目的
現時点で分かっている制約・既知不具合・回避策をまとめる。

---

## 現時点（W1）
- なし（TBD）

---

## 追記ルール
- issueを追加する場合は以下を書く：
  - 症状
  - 再現条件
  - 暫定回避策
  - 恒久対策の方針
  - 影響範囲（mode/rate/power等）

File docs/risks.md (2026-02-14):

# Risks & Mitigations

## 目的
詰みポイント（リスク）を早期に言語化し、回避策を決めておく。

---

## R1: 受光側が不安定（ノイズ/浮き/配線長）
- 症状：Rxが揺れる、同期が落ちる、CRC failが多発
- 回避策：
  - GNDを短く、配線を短く
  - 入力プル抵抗検討（必要なら）
  - ロジアナ/オシロで波形確認を“必須工程”にする
  - まず低速（0.5Mbps）で安定化してから上げる

## R2: フットプリント/配線ミスで基板が詰む
- 症状：Tx/Rxが動かない、電源が出ない
- 回避策：
  - データシート照合（フットプリント最優先）
  - テストパッド（5V/3.3V/GND/Tx_IN/Rx_OUT）を必ず入れる
  - DRC/ERCゼロ、発注前セルフレビューを docs に残す

## R3: “動くけど評価できない”状態になる（ログ/テスト不足）
- 症状：成功/失敗の比較ができない、再現できない
- 回避策：
  - W1でログ形式とテスト計画を先に置く
  - BER/PERを自動化してCSVに残す
  - 不具合は必ずチケット化し、再発防止としてテスト追加する

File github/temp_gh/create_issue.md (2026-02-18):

# TEMP_GH Issue Draft

用途:
- gh接続できない時に、AIがIssue草案と登録コマンドを書き出す出力ファイル。
- 人間は `PowerShell Command` をコピペしてIssue作成する。

## Status
- mode: draft
- reason:
- issue_url:

## Title
(skill10_issue_submit が生成)

## Body File
- (skill10_issue_submit が生成)

## Body Preview
```markdown
(skill10_issue_submit が生成)
```

## PowerShell Command
```powershell
# skill10_issue_submit 実行後にここへ出力される
```

## Bash Command
```bash
# skill10_issue_submit 実行後にここへ出力される
```

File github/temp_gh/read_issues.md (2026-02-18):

# TEMP_GH Issue Input

用途:
- gh接続できない時に、人間がIssue内容を貼る入力ファイル。
- `skill0_issue_intake` はこの内容を読んで続行する。

使い方:
1. GitHubのIssue画面を開く。
2. 下の `Issue` と `Body` と `AC` を埋める。
3. Skill0を再実行する。

## Issue
- Number:
- URL:
- Title:
- State: OPEN
- Labels:
- Author:

## Body
(ここにIssue本文を貼り付け)

## AC
- AC1:
- AC2:

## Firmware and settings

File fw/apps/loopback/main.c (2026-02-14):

#include <stdio.h>
#include "pico/stdlib.h"
#include "hardware/gpio.h"

#define TX_GPIO 2   // Pico GP2 -> Tx Vin（あなたの配線に合わせて変えてOK）
#define RX_GPIO 3   // Rx Vout -> Pico GP3

int main() {
    stdio_init_all();
    sleep_ms(1500); // USBシリアルの接続待ち（無くても動くが便利）

    gpio_init(TX_GPIO);
    gpio_set_dir(TX_GPIO, GPIO_OUT);
    gpio_put(TX_GPIO, 0);

    gpio_init(RX_GPIO);
    gpio_set_dir(RX_GPIO, GPIO_IN);
    gpio_pull_down(RX_GPIO); // Rxが開放になった時の浮き対策（保険）

    printf("loopback start. TX=%d RX=%d\n", TX_GPIO, RX_GPIO);

    uint32_t n = 0;
    while (true) {
        int tx = (n & 1);
        gpio_put(TX_GPIO, tx);

        sleep_us(50); // まずはゆっくり（W2は速度を欲張らない）

        int rx = gpio_get(RX_GPIO);
        printf("n=%lu tx=%d rx=%d\n", (unsigned long)n, tx, rx);

        n++;
        sleep_ms(100);
    }
}

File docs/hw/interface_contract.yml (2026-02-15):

meta:
  version: "0.1"
  owner: "docs/kicad_git_workflow.md"
  purpose: "Cross-step hardware interface contract source of truth"
  required_fields:
    - direction
    - voltage
    - drive
    - responsibility
    - exposed_as
  enums:
    direction: [in, out, bidir]
    voltage: [3v3, 5v, vsys, gnd, other]
    drive: [push_pull, open_drain, clock, analog]
    exposed_as: [sheet_pin, local_label, global_label, test_point, connector]
  responsibility_keys:
    - pull
    - series_r
    - esd
    - level_shift

# NOTE:
# - Add each cross-sheet signal contract under "contracts".
# - Every entry must include all required fields above.
contracts:
  - name: GP_TX
    direction: out
    voltage: 3v3
    drive: push_pull
    responsibility:
      pull: none
      series_r: step02_io
      esd: step02_io
      level_shift: not_required
    exposed_as: sheet_pin
    notes: "Example entry. Final values must be reviewed when Step02 is defined."

  - name: GP_RX
    direction: in
    voltage: 3v3
    drive: push_pull
    responsibility:
      pull: step03_mcu
      series_r: step02_io
      esd: step02_io
      level_shift: not_required
    exposed_as: sheet_pin
    notes: "Example entry. Final values must be reviewed when Step02 is defined."

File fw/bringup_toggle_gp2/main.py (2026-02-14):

from machine import Pin, PWM
import utime

pwm = PWM(Pin(2))
pwm.freq(100)
pwm.duty_u16(32768)

rx = Pin(3, Pin.IN)

edges = 0
def on_edge(pin):
    global edges
    edges += 1

rx.irq(trigger=Pin.IRQ_RISING | Pin.IRQ_FALLING, handler=on_edge)

print("IRQ edge count, expected ~200 edges/sec")

while True:
    utime.sleep(1)
    print("edges_per_sec =", edges)
    edges = 0

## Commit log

2025-12-30 docs: README.mdにプロジェクトの概要を追加
2025-12-30 docs: gitコミット用のテンプレートファイル（.gitmessage.txt）を追加
2025-12-30 <docs>:各マークダウンの初版追加
2025-12-30 docs:log_format作成
    [example_per.csv]
2025-12-30 運用用のテンプレートファイル作成
2025-12-30 ci: Git hub Actions のセットアップ初版作成
2025-12-30 docs:prのテンプレートの配置が誤っていたので修正し、.github内に移動
2025-12-31 feat: pico-sdkをサブモジュールとして追加
2025-12-31 docs:回路の部品・回路図初版作成
2025-12-31 feat:pico用のプログラムとビルド用ツール作成
2026-01-10 docs: spec.mdから部品の詳細情報をparts.mdへ移行
2026-01-12 docs:partsの購入リンクを追加@
2026-01-25 docs: 部品根拠・仕様参照・配線/測定手順を整備（AC1〜AC4）
2026-01-25 docs: parts.mdのPLR237仕様情報を修正 (Rev.1対応)
2026-01-25 docs: add PLT133/PLR237 pinout + orientation to wiring_v1.md
2026-01-26 docs: ブレッドボード用の測定点（TP）と典型NG症状を追記
2026-01-31 docs: W2-08 Pico 3V3(OUT)給電の安全メモ（mA級/NG例）を追記
2026-02-01 M0 #68: [Task][W3-00] Issue: KiCadをGitで管理する運用ドキュメント作成（MDのみ）
2026-02-01 M0 #75: [Task] [W3-00]KiCad用 .gitignore を追加して差分ノイズを防ぐ
2026-02-01 M0 #69: [Task] [W3-00] Issue: LLM前提のKiCad開発運用（“空ファイルで型を固定→差分で回路を作る”）をMD化
2026-02-07 kicad: init hw project skeleton
    [hw.kicad_pcb, hw.kicad_sch]
2026-02-08 feat(hw): add step01 power block (VBUS→prot→LDO→3V3)
    [step01_power.kicad_sch]
2026-02-14 chore: update gitignore for kicad locals and outputs
2026-02-14 chore: enforce LF for kicad files
2026-02-14 ci: generate KiCad PDF/ERC/DRC artifacts on PR
2026-02-14 test: touch step01_power
    [step01_power.kicad_sch]
2026-02-14 fix:install kicad cli
2026-02-14 test: introduce ERC violation
    [step01_power.kicad_sch]
2026-02-14 ci: fix KiCad workflow (container + change detection)
2026-02-14 ci: always run ERC/PDF for all schematics
2026-02-14 fix(hw): resolve ERC violations in step01_power
    [step01_power.kicad_sch]
2026-02-14 ci: checkout submodules for KiCad ERC
2026-02-14 docs: add bringup voltage expectations for testpoints
2026-02-14 docs: clarify PCB power bring-up and isolate breadboard procedure
2026-02-14 docs: clarify PCB power bring-up; unify power net labels
    [step01_power.kicad_sch]
2026-02-14 Issue #25: add Polyfuse_TBD project symbol and schematic updates
    [hw.kicad_sch, step01_power.kicad_sch]
2026-02-14 ci: add KiCad PR guardrails for diff-based checks
    Add diff-based PR guard script and workflow; align KiCad workflow docs.
2026-02-14 ci: invoke script via bash to avoid permission denied
    Use bash to run kicad_pr_guard.sh instead of direct execution
    to avoid needing execute bit on Windows-checked-out files.
    via [Happy](https://happy.engineering)
2026-02-14 test: protection check
    [hw.kicad_sch]
2026-02-14 Revert "Merge pull request #92 from yosukev2/test/protection-check"
    This reverts commit 82ad7c9f51440e5d2a4b89ad094d1271c24f914b, reversing
    changes made to 03317b00bd9d4ac641907b823d2f5b9ef1167334.
    [hw.kicad_sch]
2026-02-14 test: protection check 2
    [hw.kicad_sch]
2026-02-14 Revert "Merge pull request #93 from yosukev2/test/protection-check-2"
    This reverts commit 64916922ccf307a41e25ca5616cabecf585d8f22, reversing
    changes made to 94b6ece01080316bfb0e4dc0119f30e185df8bd4.
    [hw.kicad_sch]
2026-02-14 feat: add local KiCad evidence generation script and docs
    - Add scripts/kicad/gen_evidence.ps1 for local PDF/ERC/DRC generation
    - Document PR pre-submission workflow in docs/kicad_git_workflow.md
    - Output matches Actions artifacts naming convention (hw/out/)
    Closes #74
    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
2026-02-14 ci: add standalone kicad PR guard workflow
2026-02-15 tools: add circuit_synth via uv
2026-02-18 docs(temp_gh): switch to fallback I/O templates
